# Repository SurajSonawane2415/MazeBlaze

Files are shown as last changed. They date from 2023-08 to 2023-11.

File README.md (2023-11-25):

# MazeBlaze
Develop a Line following and Maze Solving bot based on PID controller that can find the shortest path in a given maze.

## Table of Contents

- [Project](#project)
   - [Table of Contents](#table-of-contents)
   - [About The Project](#about-the-project)
   - [PCB MODEL](#pcb-model)
   - [Demo](#demo)
   - [File Structure](#file-structure)
   - [Getting started](#getting-started)
   - [Future Work](#future-work)
   - [Contributors](#contributors)
   - [Resources](#resources)
   - [Acknowledgements](#acknowledgements)
   - [License](#license)

## About The Project
In this project, we will create a Line-following, Maze-solving bot that can find the shortest path in the given maze.

## Domains Explored
Artificial Intelligence, Embedded C, Control Systems, Graph Algorithms, Electronics and PCB Design

## Project Workflow
- Learning firmware development by completing [Firmware task](https://github.com/SurajSonawane2415/MazeBlaze/tree/main/task/suraj/firmware). And we also understand the firmware used in [SRA Wall-E](https://github.com/SRA-VJTI/Wall-E) and [MazeBlaze-v2](https://github.com/PritK99/MazeBlaze).
- Learning PCB design by completing the line sensor array [pcb_design](https://github.com/SurajSonawane2415/MazeBlaze/tree/main/task/suraj/pcb%20design) task.
- For bot design improvement we created a detailed sheet to make the bot design better. In which we added the advantages and disadvantages of many designs we've reviewed and chosen the best design for the MazeBlaze-v3 bot.
- PCB Design for MazeBlaze-v3 by considering all points to make the bot design better.
- Implementing left follow rule.
- Implementing path planning.
- Implementing dijkstra's algorithm.
- Implementing flood-fill algorithm.
## PCB MODEL

## Demo
### LFR algorithm(Left follow rule):

https://github.com/SurajSonawane2415/MazeBlaze/assets/129578177/a419bddd-6653-45e9-b566-6e79a6069aff

### Dijkstra's algorithm:

https://github.com/SurajSonawane2415/MazeBlaze/assets/129578177/57cf2437-57e8-468f-b269-db0ec31de83d

## File Structure

```
👨‍💻MazeBlaze-v3.1
├ 📂 Firmware
| └ 📂1_left_follow_rule //Contains code for left-follow-rule and path planning
| | ├ 📂main
| | |   ├ 📄1_left_follow_rule.c
| | |   └ 📄CMakeList.txt
| | ├ 📄CMakeList.txt
| ├ 📂2_Dijkstra //Contains code for dijkstra`s algorithm   
| └ 📂Components //Contains all the header and source files used in the project
|   ├ 📂include
|   ├ 📂src
|   ├ 📂esp-wifi-logger
|   ├ 📄CMakeList.txt
├ 📂 assets
├ 📂 documentation //Contains documentation of the project.
├ 📂 pcb_design //Contains pcb_design files of MazeBlaze-v3 board
├ 📂 task
  ├ 📂 Atharv
  | ├ 📂 firmware 
  | |  └📂 1_led_blink.c
  | |    ├ 📂main
  | |    |   ├ 📄1_led_blink.c
  | |    |  └ 📄CMakeList.txt
  | |    ├ 📄CMakeList.txt
  | ├ 📂 pcb_design
  ├ 📂 Suraj
    ├ 📂 firmware //Conatins led blink task files and documentation of the task
    |  └📂 1_led_blink.c 
    |    ├ 📂main
    |    |   ├ 📄1_led_blink.c
    |    |   └ 📄CMakeList.txt
    |    ├ 📄CMakeList.txt
    |    ├ 📄README.md
    ├ 📂 pcb_design //Conatins lsa PCB design task files and documentation of the task
```
## Getting started
### Prerequisites
To download and use this code, the minimum requirements are:
- ESP_IDF
- Windows 7 or later (64-bit), Ubuntu 20.04 or later
- Microsoft VS Code or any other IDE

### Installation
Clone the project by typing the following command in your Terminal/CommandPrompt:
      
     `git clone https://github.com/SurajSonawane2415/MazeBlaze`

Navigate to the MazeBlaze folder:
`cd MazeBlaze`

### Usage

Once the requirements are satisfied, you can easily download the project and use it on your machine. After following the above steps, use the following commands to:

To activate the IDF:
`get_idf`

To build the code:
`idf.py build`

To flash the code:
`idf.py -p (PORT) flash monitor`

## Future Work
- [ ] Implementing better algorithms like DFS/BFS.
- [ ] Achieve higher speeds by increasing the efficiency of the bot.

## Contributors
- [Suraj Sonawane](https://github.com/SurajSonawane2415)
- [Atharva Nerkar](https://github.com/ARN1954)

## Resources
- [MazeBlaze-v2](https://github.com/PritK99/MazeBlaze) GitHub repository of MazeBlaze-v2 
- [MazeBlaze-v1](https://github.com/ChinmayLonkar/MAZEBLAZE) GitHub repository of MazeBlaze-v1
- [Dikstra's](https://www-geeksforgeeks-org.cdn.ampproject.org/v/s/www.geeksforgeeks.org/printing-paths-dijkstras-shortest-path-algorithm/amp/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) Implementation of dijkstr's algorithm in c.
- [Floodfill](https://github.com/Isuru-Dissanayake/piccola) Implementation of the Floodfill algorithm (simulation).

## Acknowledgements 
- [SRA VJTI](https://sravjti.in/) Eklavya 2023
- Special thanks to our mentors [Raj Gupta](https://github.com/RajGupta17), [Prit Kanadiya](https://github.com/PritK99), and all the seniors at SRA, VJTI for their constant support and guidance throughout the project.

## License
[MIT License](https://opensource.org/license/mit/)

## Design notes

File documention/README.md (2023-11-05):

# MazeBlaze-v3.1

# TABLE OF CONTENTS
- [Left Follow Rule (LFR)](#left-follow-rule-lfr)
  - [Theory of LFR](#theory-of-lfr)
  - [Implementation of LFR](#implementation-of-lfr)
  - [Example of LFR](#example-of-lfr)
  - [Description Of Functions Used in LFR](#description-of-functions-used-in-lfr)
  - [Error Descriptions and Solution](#error-descriptions-and-solution)
  - [Problems with Left Follow Rule (LFR) algorithm](#Problems-with-Left-follow-rule-LFR-algorithm)
- [Dijkstra's algorithm](#dijkstras-algorithm)
  - [Theory of Dijkstra's](#theory-of-dijkstras)
  - [Example of Dijkstra's](#example-of-dijkstras)
  - [Implementation of Dijkstra's](#implementation-of-dijkstras)
  - [Description Of Functions Used in Dijkstra's](#description-of-functions-used-in-dijkstras)
- [Printed Circuit Board Design](#printed-circuit-board-design)
  - [Board Images](#board-images)
  - [Routing](#routing)
  - [Major components used in the PCB include](#major-components-used-in-the-pcb-include)
  - [Major Changes for Mazeblaze V3 Board](#major-changes-for-mazeblaze-v3-board)

# Left Follow Rule (LFR)
## Theory of LFR
The Left-Hand Rule (LFR), also known as the "left-follow-algorithm," is a maze-solving technique used to navigate through 2D mazes. To use LFR, you start at the entrance of a maze with your left hand touching the wall to your left. As you navigate through the maze, you follow a set of rules:

1. **Always turn left:** Whenever you reach an intersection or have a choice of paths, you make a left turn if it's possible, keeping your left hand on the wall.

2. **Go straight if a left turn is blocked:** If you come to an intersection where turning left is not an option because it leads to a wall, you continue moving straight while still touching the left wall.

3. **Take a right turn as a last resort:** If you encounter an intersection where you cannot turn left or go straight (usually because of a wall or obstacle), you take a right turn.

4. **Reverse when there are no other options:** If you find yourself in a situation where you can't turn left, go straight, or turn right, it means you've likely reached a dead end. In this case, you need to turn around and backtrack.

## Implementation of LFR
For the implementation of the left-follow rule, we need to record every turn taken by the bot by assigning numeric values to different directions. Then we need to recognize the redundant paths from the given turns.
The directions are indexed as follows:
- North: 1
- East: 2
- South: 3
- West: 4

It is important to note that the algorithm assumes that the bot initially faces the North direction. Subsequently, the other directions are determined based on the North direction. These directions are fixed concerning the world frame, and the bot continually updates its direction as it takes turns. We record the direction index into the `store_path` array, as follows:
1. **Condition for Right Turn**

   When the bot takes a right turn, it increments the `direction` by 1. This is achieved through the code:

   ```c
   direction = (direction + 1) % 4;
   if (direction == 0) direction = 4;
   ```

   This code ensures that the `direction` cycles between 1 and 4, representing North, East, South, and West, respectively.

2. **Condition for Left Turn**

   When the bot takes a left turn, it decrements the `direction` by 1. This is done using:

   ```c
   direction = (direction - 1) % 4;
   if (direction == 0) direction = 4;
   ```

   This code ensures that the `direction` cycles between 1 and 4, representing North, East, South, and West, respectively.

3. **Condition for U-Turn**

   When the bot performs a U-turn, the `direction` is decremented by 2:

   ```c
   direction = (direction - 2) % 4;
   if (direction == 0) direction = 4;
   if (direction == -1) direction = 3;
   ```

   This operation effectively represents a 180-degree turn.

4. **Condition for Moving Straight**

   When the bot continues to move straight, the `direction` remains unchanged:

   ```c
   direction = direction;
   ```

   In this case, the `direction` remains the same, signifying that the bot maintains its current orientation.

When the bot moves and follows these rules, it records its current direction in the store_path array. This helps us keep track of where the bot has been. The bot always knows which direction it's facing, even if it takes many turns.

**Code to store these directions in dry_run array:**
```c
switch (direction) 
        {
            case 1:
                printf("\t North\n");
                store_path[array_index] = 1;
                break;
            case 2:
                printf("\t East\n");
                store_path[array_index] = 2;
                break;
            case 3:
                printf("\t South\n");
                store_path[array_index] = 3;
                break;
            case 4:
                printf("\t West\n");
                store_path[array_index] = 4;
                break;
        }
//store_path[0] = 1 (The direction which the bot faces initially, is always North)
```
## Example 


Thus, for our maze, Assuming the starting position as North i.e. 1, The array store_path[ ] will store the following,

```store_path[ ] = {1, 4, 1, 2, 1, 4, 2, 1, 4, 1, 4, 2, 1, 2, 1, 4, 3, 1, 4, 3, 1, 4, 3, 2, 3, 2, 4, 3, 2, 3, 3, 4, 4, 1, 4, 2, 1, 4, 2, 1, 4, 2, 1, 4, 2, 1, 4, 2, 1}```

Here, the redundant paths are highlighted in bold

store_path[ ] = {1, 4, 1, 2, 1, **4, 2,** 1, 4, 1, **4, 2,** 1, 2, 1, 4, **3, 1,** 4, **3, 1,** 4, 3, 2, 3, **2, 4,** 3, 2, 3, 3, 4, 4, 1, **4, 2,** 1, **4, 2,** 1, **4, 2,** 1, **4, 2,** 1, **4, 2,** 1}

Thus, when we call simply_path(), it removes all these redundancies and stores the shortest path in an array called final_run[ ].

`final_run[ ] = {1,4,1,2,1,1,4,1,1,2,1,4,4,4,3,2,3,3,2,3,3,4,4,1,1,1,1,1,1}`

Thus, we make use of the simplify_path() function in our code to remove all the redundancies from store_path[] and store the shortest path in another array called final_run[].

## Description Of Functions Used

1. 
```c
void LFR()
```
   - **Description:** This function helps the robot explore a maze by following the Left Follow Rule. It detects nodes by using an LSA sensor(Line Sensor Array) and takes turns according to the type of node.

2. 
```c
void Leftturn()
```
   - **Description:** This function tells the bot to turn left by following specific rules for accurate navigation.

3. 
```c
void Rightturn()
```
   - **Description:** This function function tells the bot to turn right by following specific rules for accurate navigation.

4. 
```c
void Uturn()
```
   - **Description:** This function tells the bot to make a U-turn, which means turning around completely to go in the opposite direction, following specific navigation rules.

5. 
```c
void simplify_path()
```
   - **Description:** Removes all the redundancies from store_path[] and stores the shortest path in another array called final_run[].

6. 
```c
void final_maze_solving()
```
   - The `final_maze_solving()` function manages the actual maze-solving process. It guides the robot to follow the simplified path stored in the `final_run` array, ensuring efficient navigation and the avoidance of unnecessary movements while reaching the destination.

## Error Descriptions and Solution
**1: Task Watchdog Triggered**

- **Description:** In the above image, the "Task watchdog got triggered" error message appeared when we flashed our code on the ESP. This error occurs due to the watchdog mechanism in the ESP. The watchdog is like a timer that ensures tasks are completed within their expected time. If a task takes too long to execute, it suggests that there might be a problem with task timing.
The error was triggered because a specific task in our code was exceeding its expected execution time, causing the watchdog to trigger.
- **Solution:** To solve this issue, we added a delay of 10 milliseconds (vTaskDelay(10 / portTICK_PERIOD_MS)) after a specific function. As shown in the following snippet of code: 

```c
get_raw_lsa();
calculate_error();
calculate_correction();

left_duty_cycle = bound((GOOD_DUTY_CYCLE - correction), MIN_DUTY_CYCLE, MAX_DUTY_CYCLE);
right_duty_cycle = bound((GOOD_DUTY_CYCLE + correction), MIN_DUTY_CYCLE, MAX_DUTY_CYCLE);

set_motor_speed(MOTOR_A_1, MOTOR_FORWARD, left_duty_cycle); /* goes forward in this case */
set_motor_speed(MOTOR_A_0, MOTOR_BACKWARD, right_duty_cycle);

vTaskDelay(10 / portTICK_PERIOD_MS); //Delay
```
This allowed the task to be completed within its designated time frame, preventing the watchdog from triggering.

**2:  Unable to turn after detecting a node**
- **Description:** When the bot detects the node after that bot doesn't take a turn. This error was caused because the bot's PWM for the turn was 40, which was insufficient to turn, PWM should be greater than 55 for our case. When the PWM value was set to 40, it likely provided a relatively low average power to the motors, which resulted in the bot's motors not being able to generate enough torque or force to turn effectively.

nt-gif
- **Solution:** We solved the error by increasing the PWM (Pulse Width Modulation) value from 40 to 70 in the motor control configuration, as shown in the following snippet of code: 

 ```c
   #define PWM 85

   void Leftturn() 
   {
     set_motor_speed(MOTOR_A_0, MOTOR_FORWARD, PWM);
     set_motor_speed(MOTOR_A_1, MOTOR_BACKWARD, PWM);
     vTaskDelay(10 / portTICK_PERIOD_MS);
   }
 ```
This PWM adjustment provided the necessary power to the motors, enabling them to turn correctly after node detection. 

**3: Bot Keeps Turning, Doesn't Stop**
- **Description:**  When the bot detected a node and started turning, we added a condition to stop turning when the Line Following Sensor Array (LSA) readings turned white. The error occurred because the turning function was placed within a while loop, and causing the LSA sensor readings to not update as expected. Because of this, the condition does not get satisfied to stop turning. Because of this bot constantly starts taking turns, as shown below:

5-Sep-2023

- **Solution:** To solve this, we added a function called get_raw_lsa() to update the LSA sensor readings. as shown in the following snippet of code:  
```c
   Left turn(){
      while(stop)
      {
        get_raw_lsa();//function to update lsa readings
        set_motor_speed(MOTOR_A_0, MOTOR_BACKWARD, PWM);
        set_motor_speed(MOTOR_A_1, MOTOR_BACKWARD, PWM);

        if (lsa_reading[2] == 1000) //1000=White
        {
            set_motor_speed(MOTOR_A_0, MOTOR_STOP, 0);
            set_motor_speed(MOTOR_A_1, MOTOR_STOP, 0);
            vTaskDelay(20 / portTICK_PERIOD_MS);
            stop=0;
            break;
        }
        vTaskDelay(10 / portTICK_PERIOD_MS);
      }  
       }
```
   With this change, the condition was satisfied, allowing the bot to stop turning correctly when LSA readings became white. As shown in the following video: 

6-Sep-2023

**4: Node Misidentification**

- **Description:** The bot mistakenly identified nodes on straight paths. & after detecting a node bot starts taking. As you can see in the video below:

pt-gif

- **Solution:** To solve this, we performed PID tuning and added flags to check for nodes. When the left or right line sensors detect a white surface (e.g., 1000), a "check flag" is set to true (1). This flag rechecks the condition for nodes, and if it is false, no turn will be taken. As shown in the following snippet of code: 
```c
get_raw_lsa();
left_check = 0;
if ((lsa_reading[0] == 1000) && (lsa_reading[1] == 1000) && (lsa_reading[2] == 1000)) //Left sensor=> lsa_reading[0]
{
    // It detects PLUS NODE & Only Left Node
    printf("leftcheck1\n");
    left_check = 1;
}

if (left_check == 1 )
{
    vTaskDelay(40 / portTICK_PERIOD_MS); // delay
    get_raw_lsa();

    if ((lsa_reading[0] == 1000) && (lsa_reading[1] == 1000) && (lsa_reading[2] == 1000)) // check detected node is node or not.
    {
        left_turn = 1;
    }
    else
    {
        left_check = 0;
    }
}
```
After making all these changes, the bot does not detect nodes on a straight path, even if the bot deviates from a straight line. As you can see in the video below:

7-SEP-2023

**5: Issue with the Final Run**

- **Description:** The problem occurred during the final run., as the bot followed the directions from the `final_run` array after detecting a node. When the bot detects a node the bot should move straight(forward). However, here's where the problem came up: the bot moved forward for only 10 milliseconds. During this short time, it was still on the same node, and as a result, it detected a second node at that same node. The robot then followed the new direction from the `final_run` array. However, the bot can follow only one direction per node to complete the final run successfully. So, because of this bot is not able to complete the final run, and the final run gets destroyed. You can see this issue in the following video:

  WhatsApp Video 2023-10-28 at 03 53 01_90976d8f (1)

- **Solution:** To fix this problem, we made a change in the code. We set a condition that makes the bot keep moving straight until the entire node is ended (either the left or right sensor sees a white surface), which marks the end of a node. With this adjustment, the bot now moves straight through the entire node without detecting multiple nodes. This allowed it to complete the final run without any issues. As shown in the following snippet of code:
```c
void final_straight()
{
    get_raw_lsa();
    while (lsa_reading[0] == 1000 || lsa_reading[4] == 1000) //Left sensor==>0 Right sensor ==>4 WHITE=1000
    {
        get_raw_lsa();
        calculate_error();
        calculate_correction();
    
        left_duty_cycle = bound((GOOD_DUTY_CYCLE - correction), MIN_DUTY_CYCLE, MAX_DUTY_CYCLE);
        right_duty_cycle = bound((GOOD_DUTY_CYCLE + correction), MIN_DUTY_CYCLE, MAX_DUTY_CYCLE);
    
        set_motor_speed(MOTOR_A_1, MOTOR_FORWARD, left_duty_cycle); /*goes forward in this case*/
        set_motor_speed(MOTOR_A_0, MOTOR_BACKWARD, right_duty_cycle);
    
        vTaskDelay(10 / portTICK_PERIOD_MS);
    } 
}
```
You can see this change in action in the video below:

WhatsApp Video 2023-10-28 at 04 04 37_c621a96f (1)

## Problems with the Left Follow Rule (LFR) algorithm
The Left-Follow algorithm helps in reducing the redundancies from the path. However, the problem with the Left-Follow rule is that the entire maze does not get mapped, and thus the path obtained in final_run[ ] is not the most optimum path.

However, The problem with the Left-Follow rule is that the entire maze does not get mapped, and thus the path obtained in final_run[ ] is not the most optimum path. That's why, after this algorithm, we implemented Dijkstra's algorithm, to obtain the shortest path.

# Dijkstra's algorithm
## Theory of Dijkstra's

Dijkstra's algorithm is an algorithm for finding the shortest paths between nodes in a weighted graph. The algorithm maintains a set of visited vertices and a set of unvisited vertices. It starts at the source vertex and iteratively selects the unvisited vertex with the smallest tentative distance from the source. It then visits the neighbors of this vertex and updates their tentative distances if a shorter path is found. This process continues until the destination vertex is reached, or all reachable vertices have been visited.

## Example of Dijkstra's

Suppose we have to find the shortest distance from node 0 to node 6. We would follow these steps.

**Step 1:** Start from Node 0 and mark Node as visited as you can check in the below image visited Node is marked red.

Screenshot from 2023-10-31 23-51-32

**Step 2:** Check for adjacent Nodes, Now we have two choices (Either choose Node1 with distance 2 or choose Node 2 with distance 6 ) and choose Node with minimum distance. In this step Node 1 is the Minimum distance adjacent to Node, so mark it as visited and add up the distance.
Distance: Node 0 -> Node 1 = 2

Screenshot from 2023-10-31 23-51-51

**Step 3:** Then Move Forward and check for the adjacent Node which is Node 3, so mark it as visited and add up the distance, Now the distance will be:
Distance: Node 0 -> Node 1 -> Node 3 = 2 + 5 = 7

Screenshot from 2023-10-31 23-52-10

**Step 4:** Again we have two choices for adjacent Nodes (Either we can choose Node 4 with distance 10 or either we can choose Node 5 with distance 15) so choose Node with minimum distance. In this step Node 4 is the Minimum distance adjacent to Node, so mark it as visited and add up the distance.
Distance: Node 0 -> Node 1 -> Node 3 -> Node 4 = 2 + 5 + 10 = 17

Screenshot from 2023-10-31 23-52-29

**Step 5:** Again, Move Forward and check for the adjacent Node which is Node 6, so mark it as visited and add up the distance, Now the distance will be:
Distance: Node 0 -> Node 1 -> Node 3 -> Node 4 -> Node 6 = 2 + 5 + 10 + 2 = 19

Screenshot from 2023-10-31 23-52-43

## Implementation of Dijkstra's 
**Step I -** First we initialize 3 arrays:-
a)dist[] is an array to store the shortest distance from the source vertex to each vertex in the graph.
b)sptSet[] is a set to keep track of vertices visited in the shortest path(VISITED_NODES).
c)parent[] is an array to store the parent (predecessor) of each vertex in the shortest path.

**Step II -** Then make all elements of dist[]=infinity, sptSet[]=0, parent[]=-1.

**Step III -** 

   ```c
   for (int i = 0; i < V; i++) {
    dist[i] = INT_MAX;
    sptSet[i] = 0;
    parent[i] = -1;
    }

    dist[sourceVertex - 1] = 0;

    for (int count = 0; count < V - 1; count++) {
    int minDist = INT_MAX;
    int minIndex = -1;

    for (int v = 0; v < V; v++) {
    if (sptSet[v] == 0 && dist[v] < minDist) {
    minDist = dist[v];
    minIndex = v;
    }
    }

    sptSet[minIndex] = 1;

    for (int v = 0; v < V; v++) {
    if (!sptSet[v] && costMatrix[minIndex][v] && dist[minIndex] != INT_MAX &&
    dist[minIndex] + costMatrix[minIndex][v] < dist[v]) {
    dist[v] = dist[minIndex] + costMatrix[minIndex][v];
    parent[v] = minIndex;
    }
    }
    }
   ```

With the help of the above code, we update the dist array by storing the values which are the shortest distance of a node from the source.
Here first we make the distance of source to source 0 and then update sptSet and parent array. Then in the last for loop, we check the nearest node to source and update all other arrays. Then again go to the last loop find the nearest node from the last and store the distance between the current 2 nodes + the distance travelled before. Continue this till we reach the last node.

Finally, we get the shortest path stored in the parent array and the shortest distance stored in the distance array at index value = the endpoint.

**Step IV -** 

```c
for (int i = 0; i < size; i++)
    {
    if (finalPathArr[i + 1] - finalPathArr[i] > 1)
    {
    z = (finalPathArr[i + 1] - finalPathArr[i]) - 1;
    for (int j = 0; j < z; j++)
    {
    miss[a] = finalPathArr[i] + c;
    c++;
    a++;
    }
    c=1;
    }
    }
    for(int i=0;i<a; i++){
    k = miss[i];
    dir[k-1]=0;

    }
    for(int i=0;i<x;i++){
    printf(" %d ", dir[i]);
    }

    for(int i =0;i<x;i++){
    if(dir[i]!=0){
    final_run[y] = dir[i];
    y++;
    }
  ```

With the help of the above code, we remove the direction that the bot needs to take to reach the nodes that are not included in the shortest path. And store the directions in final_run that the bot needs to take to follow the shortest path.

## Description Of Functions Used in Dijkstra's

```c
void dijkstra()
```

It is used to find the shortest path from the source to the endpoint and the distance of the shortest path.

```c
void final_traversal()
```

It is used to make the bot travel along the shortest path.

```c
int dir[] = {1,4,1,2,2,1,4,1,4,1,2,1,1,4,1,4,1,4,3,4,3,4,3,2,3,2,3,4,4,2,3,4,3,4,4,1,1,4,4,1,4,1,4,1,4,1,4,1};
```

In it, we have stored the direction that the bot takes to reach a node.

# Printed Circuit Board (PCB) design



## Board images: 
- Front side:



- Back side:



##  Routing:
For routing of the control circuitry we used traces of 0.3mm width, for power connections we used 1.5mm (12v) & 1mm (5v), and for motor control circuitry we used  0.6mm width tracks to ensure fairly high current flow.

- Front copper routing



- Back copper layer:



- Final routing:



## Major components used in the PCB include -

| **Components** | **Description** |
| --- | --- |
| ESP32-WROOM-32E | Microcontroller |
| TB6612FNG | Motor Driver |
| QTR-8RC | Line following reflectance IR sensor array |
| Orange 11.1V 1000mAh 40C 3S | Lithium Polymer Battery | 
|IC LM2576-S-5| Buck Regulator|
|N20-12V-300 Rpm| Motor|

### Power Supply Unit :



Microcontrollers (MCUs) typically operate on 3.3V or 5V logic supply voltage, while the input voltage from the Li-Po battery for our Mazeblaze board's motor driver is 12V.    
So, to have a single input source, a power section which inter converts this 12V to 5V for MCU. This is achieved by using a step-down buck regulator.
Buck Regulator IC LM2576-S-5 is used for stepping down the voltage from 12V to 5V DC.
  
### Motor Driver :



Motors typically run on a 12V power supply, while microcontrollers (MCUs) usually output signals at either 5V or 3.3V. To make these work together, an additional external motor driver circuit is used to control motors according to the MCU input. The current and previous versions of the MazeBlaze board feature the TB6612FNG Motor Driver, a high-performance MOS-based H-Bridge motor driver.

### Protection against Reverse Voltage :
  
In the MazeBlaze Board, we use diodes to shield against reverse voltage in the power line. 12V Motor line, MCU, and buck regulator have been separated with SS34 and SS24 schottky diodes respectively.

### QTR-8RC line following reflectance IR sensor array :
  


The QTR-8RC line following reflectance IR sensor array is used to detect the white/black lined surface and it sends this data to the microcontroller ESP-32. Analyzing and processing the data received by the microcontroller ESP-32, the purpose of line following and node detection is achieved. We use this sensor because it provides precise and reliable line detection, enhancing accuracy and efficiency in tasks like line following and maze navigation. Its infrared sensor ensures stable performance across various surface conditions.

### Orange 11.1V 1000mAh 40C 3S Lithium Polymer Battery :



In the mazeblaze board, we use this battery as a power source for motors & microcontrollers. This battery is operating at 11.1 volts with a 1000mAh capacity, it provides a reliable and sustained power supply. Its high discharge rate of 40C ensures the ability to meet quick and intense power demands, making it an excellent choice for fast maze-solving tasks.

## Major Changes for Mazeblaze V3 Board
| Features | MazeBlaze-V1 | MazeBlaze-V3 |
| --- | --- | --- |
| Sensor | TCRT5000 IR SENSOR | QTR-8RC line following reflectance IR sensor array |
| Sensor Placement |on the main PCB and near the wheels|Placed apart from the main PCB, the sensor can be adjustable and not close to the wheels.|
| Battery | 3.7v Li-Po battery |11.1V 1000mAh 40C 3S Li-Po Battery |
| Power Supply Unit| MT3608 Step UP Boost Converter is used for stepping up the voltage from 3.7V DC to 6V.|Buck Regulator IC LM2576-S-5 is used for stepping down the voltage from 12V to 5V DC|

### MT3608 Step UP Boost Converter to LM2576/96 Buck Convertor
In the MazeBlaze-V1 board, we used a 3.7V battery supply for the motors, that's why we require an MT3608 boost converter to step up the voltage from 3.7V to 6V for 6V N20 motors. However, in the MazeBlaze-V3 board, we utilize an 11.1V power source for 12V N20 motors, eliminating the need for a boost converter. For the MCU (ESP), we require a 5V supply, for which we use a buck converter LM2576/96 due to their superior efficiency, higher output current, and increased reliability. The LM2576 has an efficiency of up to 92%.

### TCRT5000 IR SENSOR to QTR-8RC line following reflectance IR sensor array
In the MazeBlaze-V1 board for line following and node detection, we use TCRT5000 IR sensors but these sensors are not more efficient in maze solving. So, now in MazeBlaze-v3, we using a QTR-8RC IR sensor. QTR-8RC is chosen because of its enhanced resolution, wider range, and reduced interference, offering improved line-following precision and adaptability, vital for our maze-solving bot project.

### 3.7v Li-Po battery to 11.1V 1000mAh 40C 3S Li-Po Battery
In MazeBlaze-v1, we used a 3.7V battery, but the motors needed more voltage, so we used an MT3608 Step-Up Boost Converter to raise it to 6V. In MazeBlaze-v3, we switched to 12V N20 motors, so we used an 11.1V 1000mAh 40C 3S Li-Po Battery, it also eliminates the need for a boost converter and is also lightweight and not bulky.

### Sensor Placement on the main PCB to Placed apart from the main PCB
In MazeBlaze-v1, the line sensor array was placed very close to the wheels, which didn't allow the bot enough time to turn after detecting a node. This limitation prevented the bot from running at high speeds. To address this issue in MazeBlaze-V3, we positioned the sensors further apart from the main PCB, allowing us to adjust their placement as needed.

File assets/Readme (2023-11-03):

This folder contains all the images of PCB design and  videos of algorithm implementation.

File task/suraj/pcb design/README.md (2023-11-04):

# PCB Design Task:
In this task I designed a PCB for line sensor array(LSA) used in [SRA board](https://github.com/SRA-VJTI/sra-board-hardware-design). 
## Board images:
- Front side:
  
- Back side:
  

## Routing:
For routing of the control circuitry and power connections we used traces of 0.3mm width.
- Back copper routing


## Overview:
The Line Sensor Array (LSA) uses TCRT 5000 sensors to detect white and black lines on the surface. It then sends this data to the ESP-32 microcontroller. By analyzing and processing the data, the microcontroller ESP-32 accomplishes the task of line following.

## TCRT 5000
The TCRT 5000 is an optical sensor module commonly used for detecting the presence of objects or lines. It consists of an infrared (IR) emitter and a phototransistor. The emitter emits infrared light, which bounces off objects or surfaces and is detected by the phototransistor. The amount of reflected light is used to determine the proximity of an object or the presence of a surface, typically a white or black line. TCRT 5000 sensors are often employed in applications like line-following bot.



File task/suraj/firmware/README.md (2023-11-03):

# Firmware task
In this task, we write an ESP-IDF code to blink an LED without using the "sra_board.h" header file, which is used in the ["Wall-E 1_led_blink"](https://github.com/SRA-VJTI/Wall-E/tree/master/1_led_blink) code.

## Terms used
### GPIO Configuration
GPIO (General Purpose Input/Output) pins on microcontrollers are often configured to either input or output mode. When a pin is configured as an output, it can be used to control external devices like LEDs, motors, or sensors. Configuration typically involves specifying the pin, its mode, and any additional settings like pull-up or pull-down resistors.
**Code Snippet for GPIO Configuration**:
```c
// Configuration for GPIO pin 12 as an output with a pull-down resistor
gpio_config_t io_conf;
io_conf.pin_bit_mask = (1ULL << GPIO_NUM_12);  // Pin bitmask
io_conf.mode = GPIO_MODE_OUTPUT;  // Set the pin as an output
io_conf.pull_up_en = 0;  // Disable pull-up resistor
io_conf.pull_down_en = 1;  // Enable pull-down resistor
io_conf.intr_type = GPIO_INTR_DISABLE;  // Disable interrupt handling

esp_err_t err = gpio_config(&io_conf);
if (err != ESP_OK) {
   // Handle configuration error
}
```
In this snippet, `gpio_config_t` is a structure used to configure the GPIO pins. The `io_conf` structure specifies the pin bitmask, mode (output in this case), pull-up and pull-down settings, and interrupt handling. If the configuration fails, an error can be handled accordingly.

### Bit Masking
Bit masking is a technique used to manipulate and extract specific bits within a binary number. It's often used in microcontroller programming to set or clear individual bits in a register, which can control various hardware components.
For example, bit masking is use to set a specific bit to 1 while keeping all other bits unchanged. In C, the | (OR) operator for setting bits and the & (AND) operator to clear bits.
**Code Snippet for Bit Masking**:
```c
// Setting bit 2 to 1, assuming a 3-bit binary number
uint8_t data = 0b00000100;  // Binary representation
uint8_t bitmask = 0b00000100;  // Mask with a 1 in the desired bit
data |= bitmask;  // Setting the bit to 1

// Clearing bit 3 to 0
uint8_t data2 = 0b00001000;
uint8_t bitmask2 = 0b11110111;  // Mask with 0 in the desired bit
data2 &= bitmask2;  // Clearing the bit to 0
```
These snippets demonstrate bit masking for manipulating individual bits in binary data and configuring a GPIO pin for output with specific settings.

## Output:
task (1)

## Refernces
- [SRA Embedded system study group](https://sravjti.in/embedded-systems-study-group/week5/week5.html) refernce for bit masking.
- [ESP-32 GPIO configuration guide](https://docs.espressif.com/projects/esp-idf/en/latest/esp32/api-reference/peripherals/gpio.html) GPIO configuration refernce.

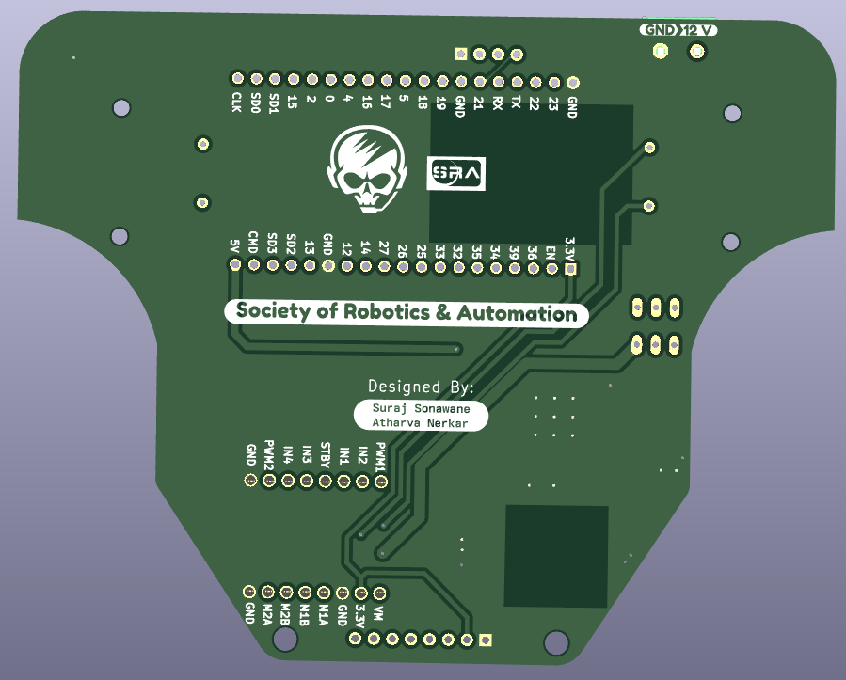
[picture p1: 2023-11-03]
assets/back.png

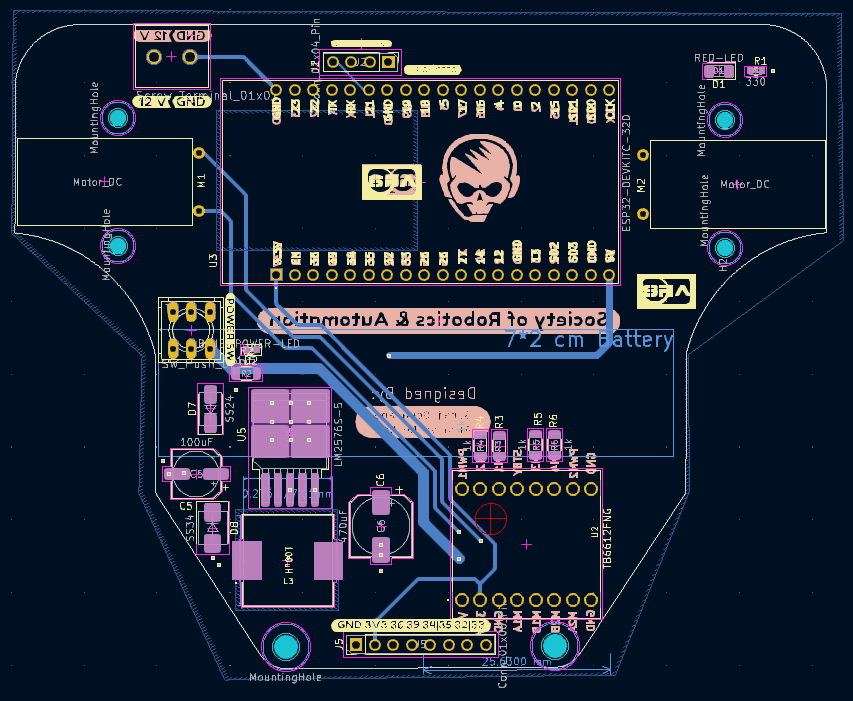
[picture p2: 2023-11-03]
assets/Bcu.png

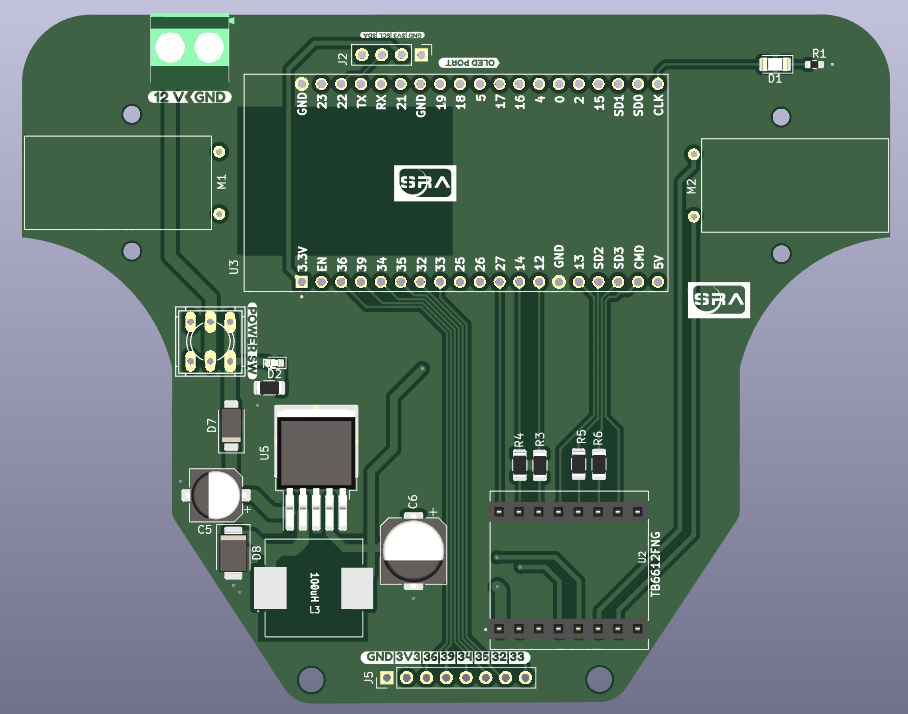
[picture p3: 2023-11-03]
assets/front.png

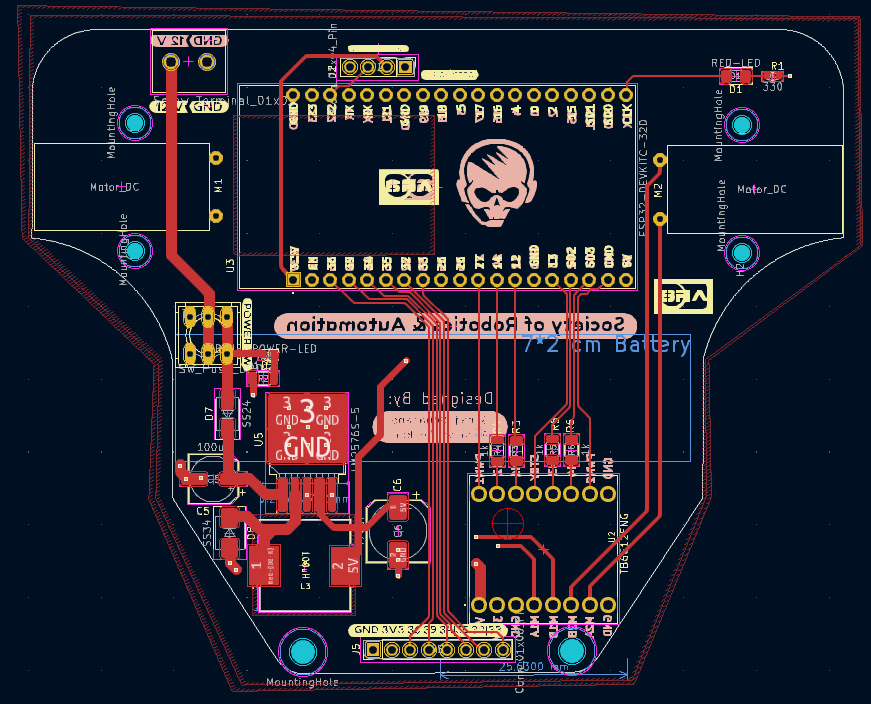
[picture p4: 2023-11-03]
assets/Fcu.png

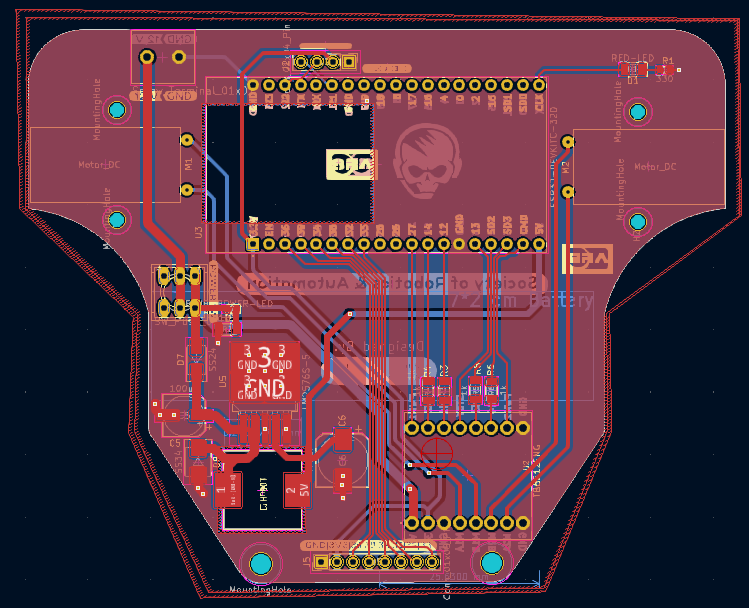
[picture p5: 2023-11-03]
assets/routing.png

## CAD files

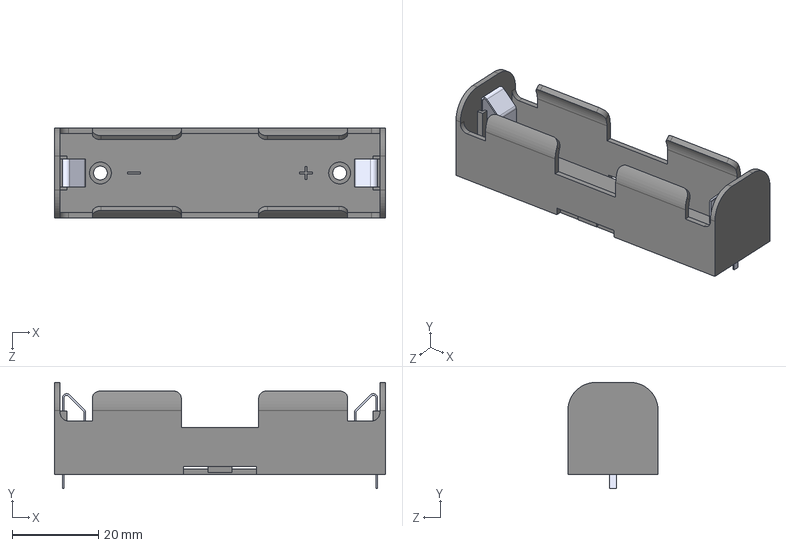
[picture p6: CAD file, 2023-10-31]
pcb_design/3d_models/BK-18650-PC2.step
77.0 x 24.7 x 21.0 mm

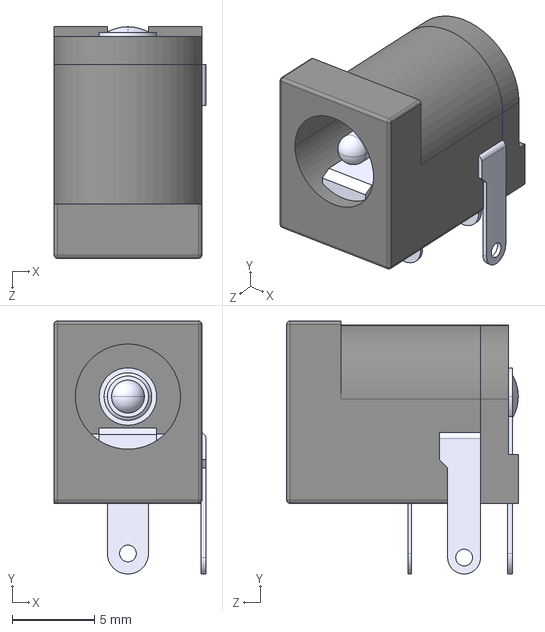
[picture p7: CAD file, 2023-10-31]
pcb_design/3d_models/CON-SOCJ-2155--3DModel-STEP-56544.STEP
9.25 x 15.4 x 14.1 mm

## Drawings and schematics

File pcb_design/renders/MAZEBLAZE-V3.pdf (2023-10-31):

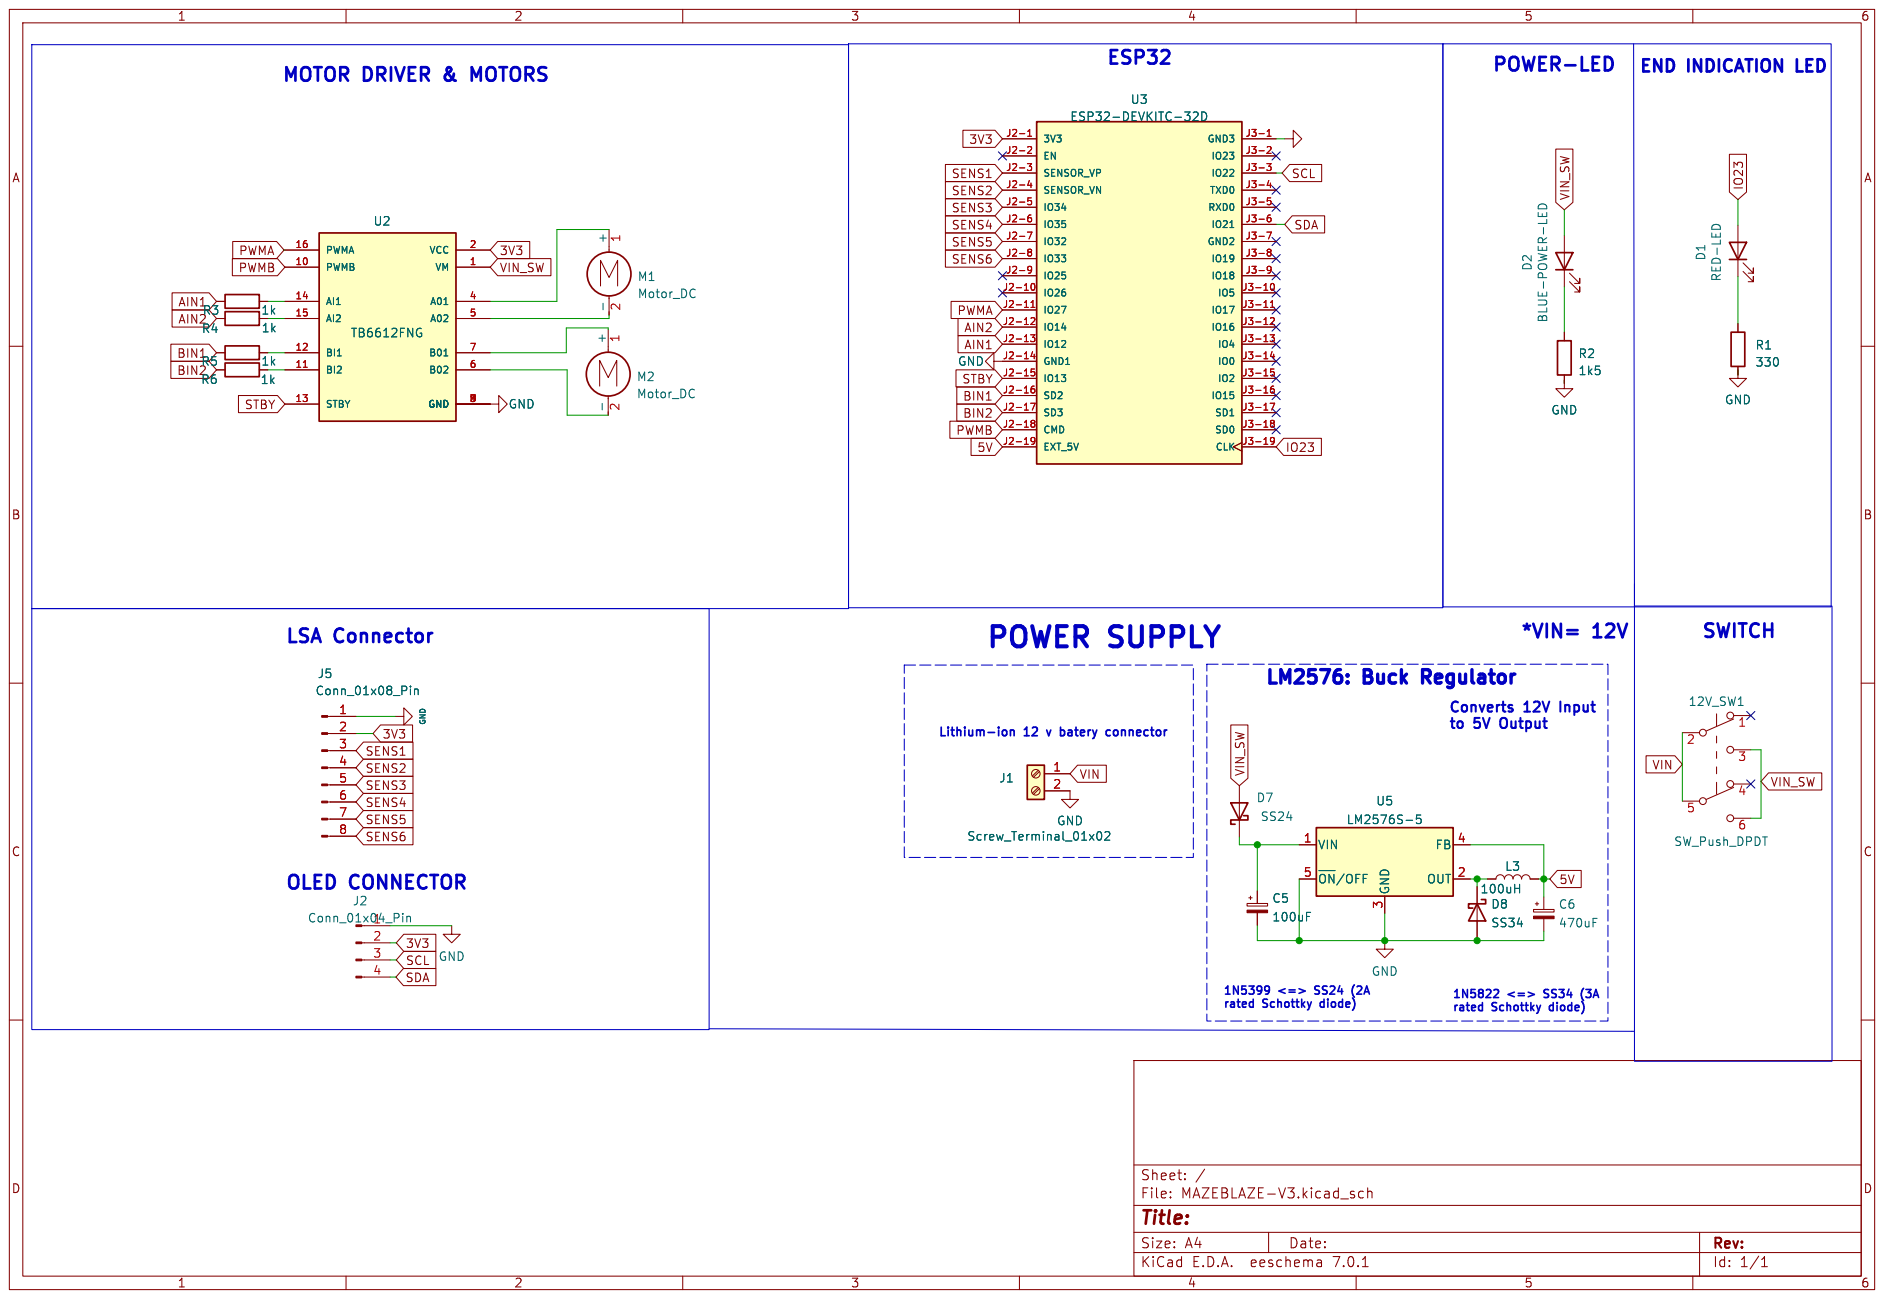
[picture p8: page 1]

rated Schottky diode) MOTOR DRIVER & MOTORS

330 GND D2 BLUE-POWER-LED GND

LM2576: Buck Regulator Converts 12V Input

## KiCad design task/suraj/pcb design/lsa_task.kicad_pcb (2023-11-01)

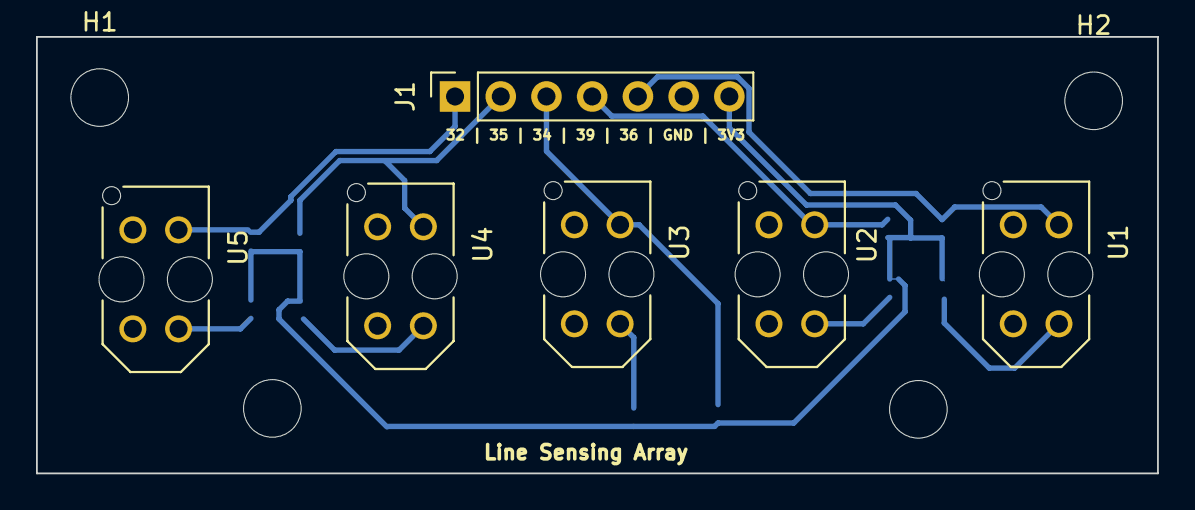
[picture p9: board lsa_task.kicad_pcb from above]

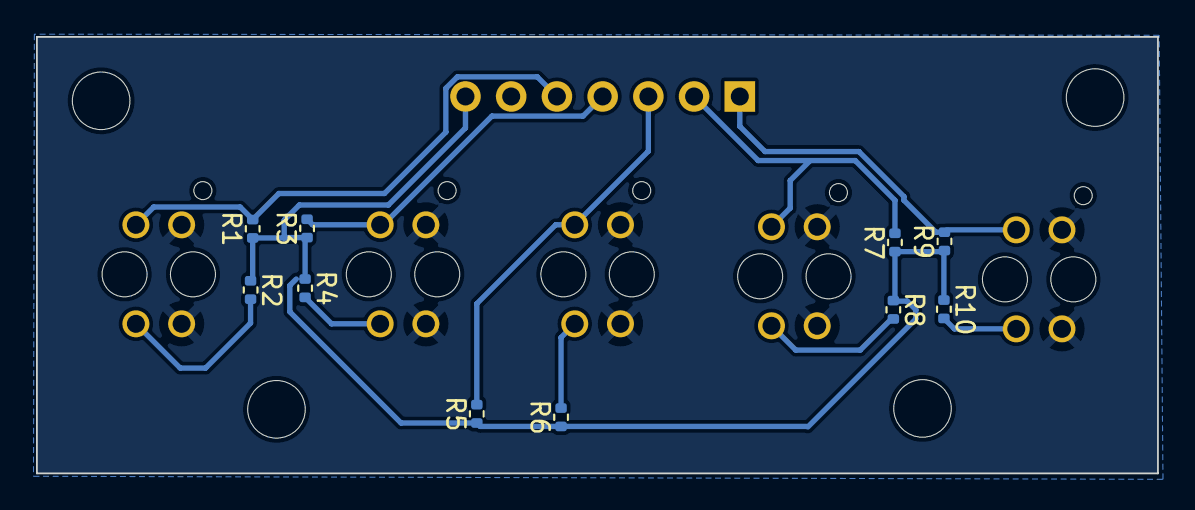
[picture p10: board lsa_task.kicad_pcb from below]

Board: 2 copper layers, 62.3 x 24.2 mm, 20 parts (10 on the bottom side), 12 nets.

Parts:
H1, H2, H3, H4: MountingHole_Pad; MountingHole_3.2mm_M3
J1: Conn_01x07_Pin; PinSocket_1x07_P2.54mm_Vertical
R1, R3, R5, R7, R9: 4k7; R_0402_1005Metric
R2, R4, R6, R8, R10: 1K; R_0402_1005Metric
U1, U2, U3, U4, U5: TCRT5000; OPTO_TCRT5000

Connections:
3V3: J1.7, R1.1, R2.1, R3.1, R4.1, R5.1, R6.1, R7.1, R8.1, R9.1, R10.1
A0_36: J1.5, R1.2, U1.COLL
A1_39: J1.4, R3.2, U2.COLL
A2_34: J1.3, R5.2, U3.COLL
A3_35: J1.2, R7.2, U4.COLL
A4_32: J1.1, R9.2, U5.COLL
GND: J1.6, U1.CATH, U1.E, U2.CATH, U2.E, U3.CATH, U3.E, U4.CATH, U4.E, U5.CATH, U5.E
unnamed: R2.2, U1.A
unnamed: R4.2, U2.A
unnamed: R6.2, U3.A
unnamed: R8.2, U4.A
unnamed: R10.2, U5.A

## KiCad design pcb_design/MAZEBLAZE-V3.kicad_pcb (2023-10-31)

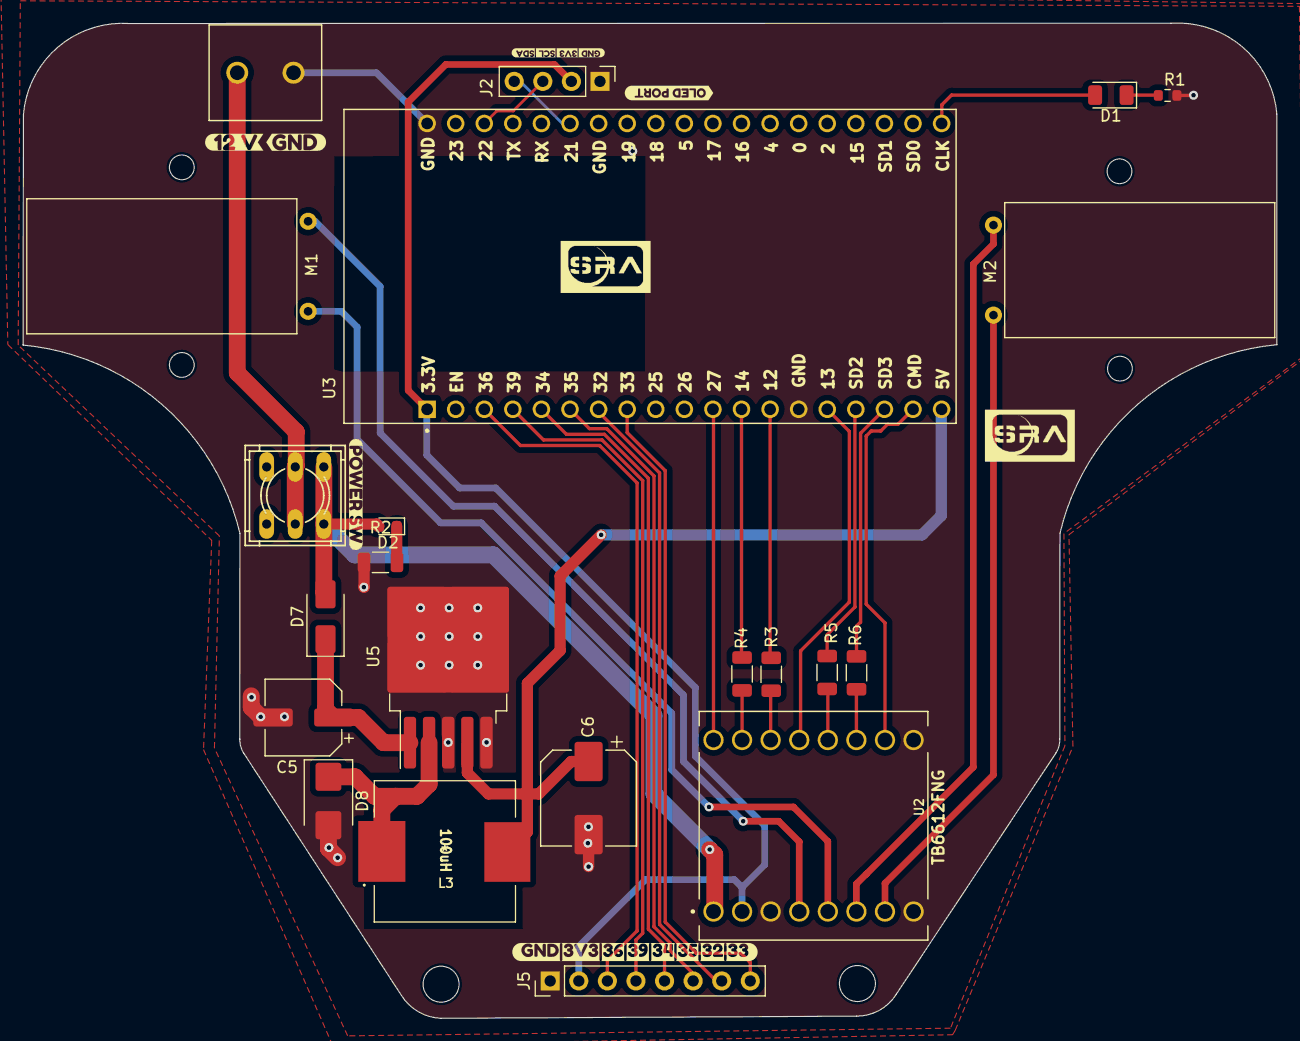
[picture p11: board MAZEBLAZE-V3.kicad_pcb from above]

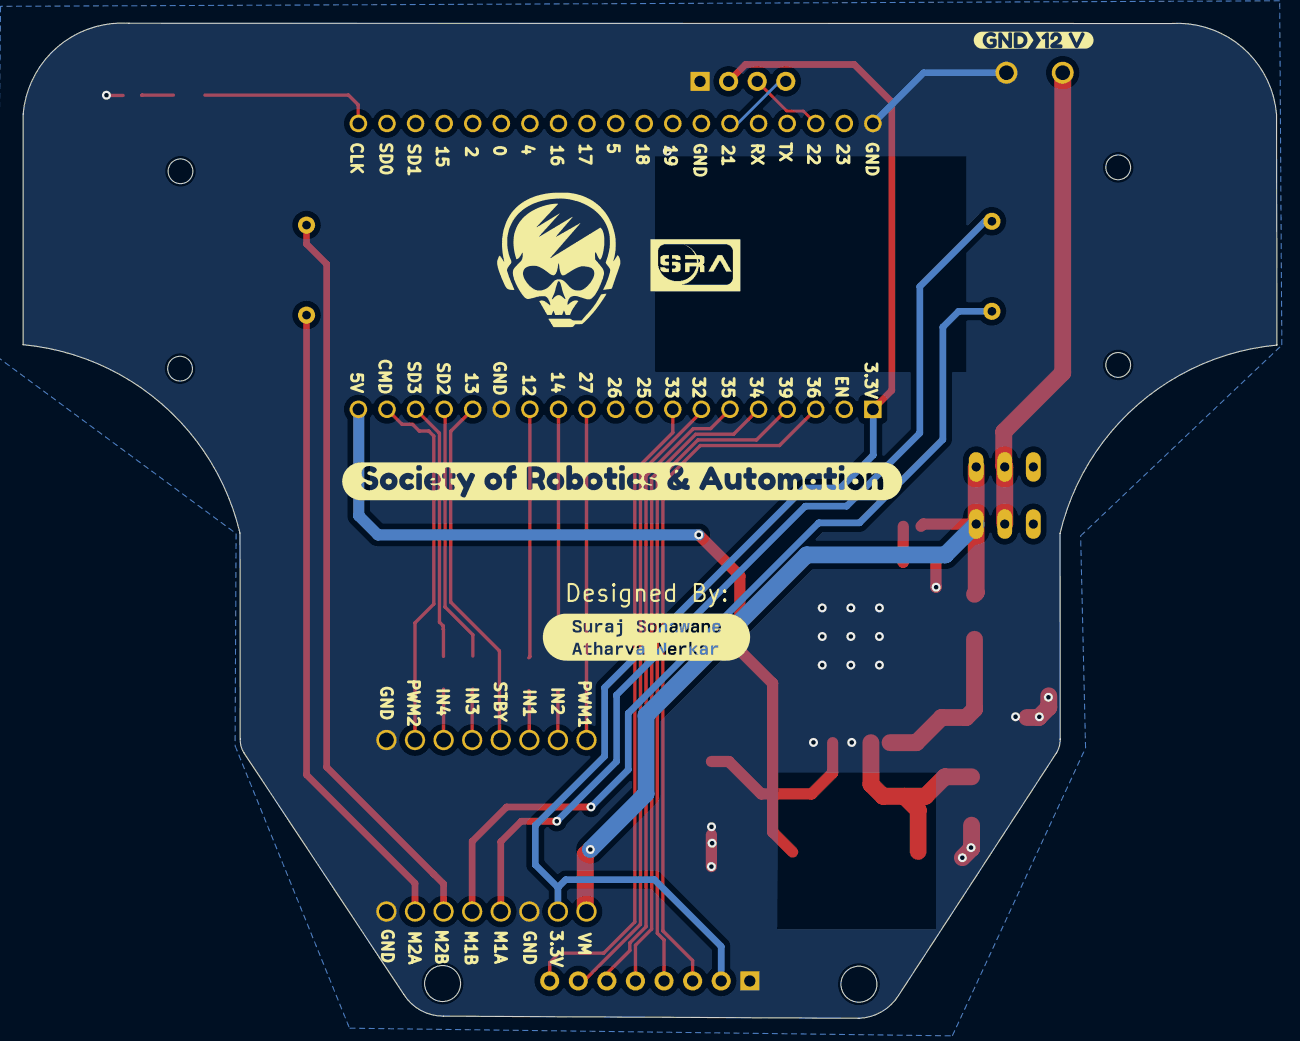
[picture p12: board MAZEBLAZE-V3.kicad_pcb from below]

Board: 2 copper layers, 111.4 x 88.4 mm, 38 parts (4 on the bottom side), 33 nets.

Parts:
12V_SW1: SW_Push_DPDT; dpdt_sw_2x03_tht
C5: 100uF; CP_Elec_6.3x7.7
C6: 470uF; CP_Elec_8x10
D1: RED-LED; LED_1206_3216Metric
D2: BLUE-POWER-LED; LED_0603_1608Metric
D7: SS24; D_SMA
D8: SS34; D_SMB
H1, H2#2, H3, H4: MountingHole; MountingHole_2.2mm_M2
H2, H5: MountingHole; MountingHole_3.2mm_M3
J1: Screw_Terminal_01x02; 12V_1x02_tht
J2: Conn_01x04_Pin; PinHeader_1x04_P2.54mm_Vertical
J5: Conn_01x08_Pin; PinHeader_1x08_P2.54mm_Vertical
L3: 100uH; CDRH127_inductor_smd
M1, M2: Motor_DC; N20_Motor
R1: 330; R_0603_1608Metric
R2: 1k5; R_1206_3216Metric
R3, R4, R5, R6: 1k; R_1206_3216Metric
U2: TB6612FNG; TB6612FNG_2
U3: ESP32-DEVKITC-32D; MODULE_ESP32-DEVKITC-32D
U5: LM2576S-5; TO-263-5_TabPin3
kibuzzard-61F7FB1D: G***; kibuzzard-61F7FB1D
kibuzzard-61F7FBA3: G***; kibuzzard-61F7FBA3
kibuzzard-61F7FBC2: G***; kibuzzard-61F7FBC2
kibuzzard-61F7147A: G***; kibuzzard-61F7147A
kibuzzard-61F71491: G***; kibuzzard-61F71491
kibuzzard-637A1A13: G***; kibuzzard-637A1A13
kibuzzard-653BE6A4: G***; kibuzzard-653BE6A4
kibuzzard-653BE7A2: G***; kibuzzard-653BE7A2
kibuzzard-653BEE79: G***; kibuzzard-653BEE79
kibuzzard-653E5949: G***; kibuzzard-653E5949

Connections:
3V3: J2.2, J5.2, U2.2 (VCC), U3.J2-1 (3V3)
5V: C6.1, L3.2, U3.J2-19 (EXT_5V), U5.4 (FB)
AIN1: R3.1, U3.J2-13 (IO12)
AIN2: R4.1, U3.J2-12 (IO14)
BIN1: R5.1, U3.J2-16 (SD2)
BIN2: R6.1, U3.J2-17 (SD3)
GND: C5.2, C6.2, D8.2 (A), J1.2, J2.1, J5.1, R1.2, R2.2, U2.3 (GND), U2.8 (GND), U2.9 (GND), U3.J2-14 (GND1), U3.J3-1 (GND3), U5.3 (GND), U5.5 (~ON/OFF)
IO23: D1.2 (A), U3.J3-19 (CLK)
unnamed: D1.1 (K), R1.1
unnamed: D2.1 (K), R2.1
unnamed: C5.1, D7.1 (K), U5.1 (VIN)
unnamed: D8.1 (K), L3.1, U5.2 (OUT)
unnamed: M1.1 (+), U2.4 (A01)
unnamed: M1.2 (-), U2.5 (A02)
unnamed: M2.1 (+), U2.7 (B01)
unnamed: M2.2 (-), U2.6 (B02)
unnamed: R3.2, U2.14 (AI1)
unnamed: R4.2, U2.15 (AI2)
unnamed: R5.2, U2.12 (BI1)
unnamed: R6.2, U2.11 (BI2)
PWMA: U2.16 (PWMA), U3.J2-11 (IO27)
PWMB: U2.10 (PWMB), U3.J2-18 (CMD)
SCL: J2.3, U3.J3-3 (IO22)
SDA: J2.4, U3.J3-6 (IO21)
SENS1: J5.3, U3.J2-3 (SENSOR_VP)
SENS2: J5.4, U3.J2-4 (SENSOR_VN)
SENS3: J5.5, U3.J2-5 (IO34)
SENS4: J5.6, U3.J2-6 (IO35)
SENS5: J5.7, U3.J2-7 (IO32)
SENS6: J5.8, U3.J2-8 (IO33)
STBY: U2.13 (STBY), U3.J2-15 (IO13)
VIN: 12V_SW1.2 (B), 12V_SW1.5 (B), J1.1
VIN_SW: 12V_SW1.3 (C), 12V_SW1.6 (C), D2.2 (A), D7.2 (A), U2.1 (VM)

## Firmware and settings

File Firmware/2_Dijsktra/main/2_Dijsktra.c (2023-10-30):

#include <stdio.h>
#include <stdlib.h>
#include "mazeblaze3.h"
#include "tuning_http_server.h"
#include "driver/gpio.h"

float error = 0, prev_error = 0, difference, cumulative_error, correction;
float left_duty_cycle = 0, right_duty_cycle = 0;

float kp = 35, ki = 0.01, kd = 60;

const int weights[5] = {3, 1, 0, -1, -3};

int final_run[50];
int array_index = 1;
int f=1;
TaskHandle_t taskhandle1 = NULL;

#define INFINITY_A 999
#define V 48

/*This method involves tuning kp , ski ,kd physically*/
#define GOOD_DUTY_CYCLE 91
#define MIN_DUTY_CYCLE 61
#define MAX_DUTY_CYCLE 86
int path_length = 0;
int enable_path_matrix=1;
int stop_path_matrix=1;


/*FINAL TURN FLAGS*/
int left_final_check=0;
int right_final_check=0;
int final_left_turn_check=0;
int final_right_turn_check=0;
int take_final_right_turn=0;
int take_final_left_turn=0;
int take_straight=0;
int stop=0;
int x = 0;
int left_check = 0;
int right_check = 0;
int left_turn_check = 0;
int left_turn=0;
int right_turn = 0;
int left_tune = 0;
int only_right = 0;
int uturn_tune = 0;
int right_tune = 0;
int Check_End=0;

#define PWM 85
int rotation1 = 0;
bool rotation2 = false;

int costMatrix[V][V] = {
 {0, 2, 0, 0, 0, 0, 0, 0, 0, 0, 0, 0, 0, 0, 0, 0, 0, 0, 0, 0, 0, 0, 0, 0, 0, 0, 0, 0, 0, 0, 0, 0, 0, 0, 0, 0, 0, 0, 0, 0, 0, 0, 0, 0, 0, 0, 0, 0},
 {0, 0, 2, 0, 0, 0, 0, 0, 0, 0, 0, 0, 0, 0, 0, 0, 0, 0, 0, 0, 0, 0, 0, 0, 0, 0, 0, 0, 0, 0, 0, 0, 0, 0, 0, 0, 0, 0, 0, 0, 0, 0, 0, 0, 0, 0, 0, 0},
 {0, 0, 0, 2, 0, 0, 0, 0, 0, 0, 0, 0, 0, 0, 0, 0, 0, 0, 0, 0, 0, 0, 0, 0, 0, 0, 0, 0, 0, 0, 0, 0, 0, 0, 0, 0, 0, 0, 0, 0, 0, 0, 0, 0, 0, 0, 0, 0},
 {0, 0, 0, 0, 2, 2, 0, 0, 0, 0, 0, 0, 0, 0, 0, 0, 0, 0, 0, 0, 0, 0, 0, 0, 0, 0, 0, 0, 0, 0, 0, 0, 0, 0, 0, 0, 0, 0, 0, 0, 0, 0, 0, 0, 0, 0, 0, 0},
 {0, 0, 0, 0, 0, 0, 0, 0, 0, 0, 0, 0, 0, 0, 0, 0, 0, 0, 0, 0, 0, 0, 0, 0, 0, 0, 0, 0, 0, 0, 0, 0, 0, 0, 0, 0, 0, 0, 0, 0, 0, 0, 0, 0, 0, 0, 0, 0},
 {0, 0, 0, 0, 0, 0, 2, 2, 0, 0, 0, 0, 0, 0, 0, 0, 0, 0, 0, 0, 0, 0, 0, 0, 0, 0, 0, 0, 0, 0, 0, 0, 0, 0, 0, 0, 0, 0, 0, 0, 0, 0, 0, 0, 0, 0, 0, 0},
 {0, 0, 0, 0, 0, 0, 0, 0, 0, 0, 0, 0, 0, 0, 0, 0, 0, 0, 0, 0, 0, 0, 0, 0, 0, 0, 0, 0, 0, 0, 0, 0, 0, 0, 0, 0, 0, 0, 0, 0, 0, 0, 0, 0, 0, 0, 0, 0},
 {0, 0, 0, 0, 0, 0, 0, 0, 2, 2, 2, 0, 0, 0, 0, 0, 0, 0, 0, 0, 0, 0, 0, 0, 0, 0, 0, 0, 0, 0, 0, 0, 0, 0, 0, 0, 0, 0, 0, 0, 0, 0, 0, 0, 0, 0, 0, 0},
 {0, 0, 0, 0, 0, 0, 0, 0, 0, 0, 0, 2, 0, 0, 0, 0, 0, 0, 0, 0, 0, 0, 0, 0, 0, 0, 0, 0, 0, 0, 0, 0, 0, 0, 0, 0, 0, 0, 0, 0, 0, 0, 0, 0, 0, 0, 0, 0},
 {0, 0, 0, 0, 0, 0, 0, 0, 0, 0, 0, 0, 0, 0, 0, 0, 0, 0, 0, 0, 0, 0, 0, 0, 0, 0, 0, 0, 0, 0, 0, 0, 0, 0, 0, 0, 0, 0, 0, 0, 0, 0, 0, 0, 0, 0, 0, 0},
 {0, 0, 0, 0, 0, 0, 0, 0, 0, 0, 0, 0, 2, 0, 0, 0, 0, 0, 0, 0, 0, 0, 0, 0, 0, 0, 0, 0, 0, 0, 0, 0, 0, 0, 0, 0, 0, 0, 0, 0, 0, 0, 0, 0, 0, 0, 0, 0},
 {0, 0, 0, 0, 0, 0, 0, 0, 0, 0, 0, 0, 0, 2, 2, 0, 0, 0, 0, 0, 0, 0, 0, 0, 0, 0, 0, 0, 0, 0, 0, 0, 0, 0, 0, 0, 0, 0, 0, 0, 0, 0, 0, 0, 0, 0, 0, 0},
 {0, 0, 0, 0, 0, 0, 0, 0, 0, 0, 0, 0, 0, 0, 0, 2, 0, 0, 0, 0, 0, 0, 0, 0, 0, 0, 0, 0, 0, 0, 0, 0, 0, 0, 0, 0, 0, 0, 0, 0, 0, 0, 0, 0, 0, 0, 0, 0},
 {0, 0, 0, 0, 0, 0, 0, 0, 0, 0, 0, 0, 0, 0, 0, 0, 0, 0, 0, 0, 0, 0, 0, 0, 0, 0, 0, 0, 0, 0, 0, 0, 0, 0, 0, 0, 0, 0, 0, 0, 0, 0, 0, 0, 0, 0, 0, 0},
 {0, 0, 0, 0, 0, 0, 0, 0, 0, 0, 0, 0, 0, 0, 0, 2, 0, 0, 0, 0, 0, 0, 0, 0, 0, 0, 0, 0, 0, 0, 0, 0, 0, 0, 0, 0, 0, 0, 0, 0, 0, 0, 0, 0, 0, 0, 0, 0},
 {0, 0, 0, 0, 0, 0, 0, 0, 0, 0, 0, 0, 0, 0, 0, 0, 2, 0, 0, 0, 0, 0, 0, 0, 0, 0, 0, 0, 0, 0, 0, 0, 0, 0, 0, 0, 0, 0, 0, 0, 0, 0, 0, 0, 0, 0, 0, 0},
 {0, 0, 0, 0, 0, 0, 0, 0, 0, 0, 0, 0, 0, 0, 0, 0, 0, 3, 0, 0, 0, 0, 0, 0, 0, 0, 0, 0, 0, 0, 0, 0, 0, 0, 0, 0, 0, 0, 0, 0, 0, 0, 0, 0, 0, 0, 0, 0},
 {0, 0, 0, 0, 0, 0, 0, 0, 0, 0, 0, 0, 0, 0, 0, 0, 0, 0, 2, 2, 0, 0, 0, 0, 0, 0, 0, 0, 0, 0, 0, 0, 0, 0, 0, 0, 0, 0, 0, 0, 0, 0, 0, 0, 0, 0, 0, 0},
 {0, 0, 0, 0, 0, 0, 0, 0, 0, 0, 0, 0, 0, 0, 0, 0, 0, 0, 0, 0, 0, 0, 0, 0, 0, 0, 0, 0, 0, 0, 0, 0, 0, 0, 0, 0, 0, 0, 0, 0, 0, 0, 0, 0, 0, 0, 0, 0},
 {0, 0, 0, 0, 0, 0, 0, 0, 0, 0, 0, 0, 0, 0, 0, 0, 0, 0, 0, 0, 2, 2, 0, 0, 0, 0, 0, 0, 0, 0, 0, 0, 0, 0, 0, 0, 0, 0, 0, 0, 0, 0, 0, 0, 0, 0, 0, 0},
 {0, 0, 0, 0, 0, 0, 0, 0, 0, 0, 0, 0, 0, 0, 0, 0, 0, 0, 0, 0, 0, 0, 0, 0, 0, 0, 0, 0, 0, 0, 0, 0, 0, 0, 0, 0, 0, 0, 0, 0, 0, 0, 0, 0, 0, 0, 0, 0},
 {0, 0, 0, 0, 0, 0, 0, 0, 0, 0, 0, 0, 0, 0, 0, 0, 0, 0, 0, 0, 0, 0, 4, 0, 0, 0, 0, 0, 0, 0, 0, 0, 0, 0, 0, 0, 0, 0, 0, 0, 0, 0, 0, 0, 0, 0, 0, 0},
 {0, 0, 0, 0, 0, 0, 0, 0, 0, 0, 0, 0, 0, 0, 0, 0, 0, 0, 0, 0, 0, 0, 0, 2, 0, 0, 0, 0, 0, 0, 0, 0, 0, 0, 0, 0, 0, 0, 0, 0, 0, 0, 0, 0, 0, 0, 0, 0},
 {0, 0, 0, 0, 0, 0, 0, 0, 0, 0, 0, 0, 0, 0, 0, 0, 0, 0, 0, 0, 0, 0, 0, 0, 2, 0, 0, 0, 0, 0, 0, 0, 0, 0, 0, 0, 0, 0, 0, 0, 0, 0, 0, 0, 0, 0, 0, 0},
 {0, 0, 0, 0, 0, 0, 0, 0, 0, 0, 0, 0, 0, 0, 0, 0, 0, 0, 0, 0, 0, 0, 0, 0, 0, 2, 2, 2, 0, 0, 0, 0, 0, 0, 0, 0, 0, 0, 0, 0, 0, 0, 0, 0, 0, 0, 0, 0},
 {0, 0, 0, 0, 0, 0, 0, 0, 0, 0, 0, 0, 0, 0, 0, 0, 0, 0, 0, 0, 0, 0, 0, 0, 0, 0, 0, 0, 0, 0, 0, 0, 0, 0, 0, 0, 0, 0, 0, 0, 0, 0, 0, 0, 0, 0, 0, 0},
 {0, 0, 0, 0, 0, 0, 0, 0, 0, 0, 0, 0, 0, 0, 0, 0, 0, 0, 0, 0, 0, 0, 0, 0, 0, 0, 0, 0, 0, 2, 0, 0, 0, 0, 0, 0, 0, 0, 0, 0, 0, 0, 0, 0, 0, 0, 0, 0},
 {0, 0, 0, 0, 0, 0, 0, 0, 0, 0, 0, 0, 0, 0, 0, 0, 0, 0, 0, 0, 0, 0, 0, 0, 0, 0, 0, 0, 2, 0, 0, 0, 0, 0, 0, 0, 0, 0, 0, 0, 0, 0, 0, 0, 0, 0, 0, 0},
 {0, 0, 0, 0, 0, 0, 0, 0, 0, 0, 0, 0, 0, 0, 0, 0, 0, 0, 0, 0, 0, 0, 0, 0, 0, 0, 2, 0, 0, 0, 0, 0, 0, 0, 0, 0, 0, 0, 0, 0, 0, 0, 0, 0, 0, 0, 0, 0},
 {0, 0, 0, 0, 0, 0, 0, 0, 0, 0, 0, 0, 0, 0, 0, 0, 0, 0, 0, 0, 0, 0, 0, 0, 0, 0, 0, 0, 0, 0, 2, 0, 0, 0, 0, 0, 0, 0, 0, 0, 0, 0, 0, 0, 0, 0, 0, 0},
 {0, 0, 0, 0, 0, 0, 0, 0, 0, 0, 0, 0, 0, 0, 0, 0, 0, 0, 0, 0, 0, 0, 0, 0, 0, 0, 0, 0, 0, 0, 0, 4, 4, 0, 0, 0, 0, 0, 0, 0, 0, 0, 0, 0, 0, 0, 0, 0},
 {0, 0, 0, 0, 0, 0, 0, 0, 0, 0, 0, 0, 0, 0, 0, 0, 0, 0, 0, 0, 0, 0, 0, 0, 0, 0, 0, 0, 0, 0, 0, 0, 0, 0, 0, 0, 0, 0, 0, 0, 0, 0, 0, 0, 0, 0, 0, 0},
 {0, 0, 0, 0, 0, 0, 0, 0, 0, 0, 0, 0, 0, 0, 0, 0, 0, 0, 0, 0, 0, 0, 0, 0, 0, 0, 0, 0, 0, 0, 0, 0, 0, 2, 0, 0, 0, 0, 0, 0, 0, 0, 0, 0, 0, 0, 0, 0},
 {0, 0, 0, 0, 0, 0, 0, 0, 0, 0, 0, 0, 0, 0, 0, 0, 0, 0, 0, 0, 0, 0, 0, 0, 0, 0, 0, 0, 0, 0, 0, 0, 0, 0, 4, 2, 0, 0, 0, 0, 0, 0, 0, 0, 0, 0, 0, 0},
 {0, 0, 0, 0, 0, 0, 0, 0, 0, 0, 0, 0, 0, 0, 0, 0, 0, 0, 0, 0, 0, 0, 0, 0, 0, 0, 0, 0, 0, 0, 0, 0, 0, 0, 0, 0, 2, 0, 0, 0, 0, 0, 0, 0, 0, 0, 0, 0},
 {0, 0, 0, 0, 0, 0, 0, 0, 0, 0, 0, 0, 0, 0, 0, 0, 0, 0, 0, 0, 0, 0, 0, 0, 0, 0, 0, 0, 0, 0, 0, 0, 0, 0, 0, 0, 0, 2, 0, 0, 0, 0, 0, 0, 0, 0, 0, 0},
 {0, 0, 0, 0, 0, 0, 0, 0, 0, 0, 0, 0, 0, 0, 0, 0, 0, 0, 0, 0, 0, 0, 0, 0, 0, 0, 0, 0, 0, 0, 0, 0, 0, 0, 0, 0, 0, 0, 2, 2, 0, 0, 0, 0, 0, 0, 0, 0},
 {0, 0, 0, 0, 0, 0, 0, 0, 0, 0, 0, 0, 0, 0, 0, 0, 0, 0, 0, 0, 0, 0, 0, 0, 0, 0, 0, 0, 0, 0, 0, 0, 0, 0, 0, 0, 0, 0, 0, 0, 0, 0, 0, 0, 0, 0, 0, 0},
 {0, 0, 0, 0, 0, 0, 0, 0, 0, 0, 0, 0, 0, 0, 0, 0, 0, 0, 0, 0, 0, 0, 0, 0, 0, 0, 0, 0, 0, 0, 0, 0, 0, 0, 0, 0, 0, 0, 0, 0, 0, 0, 0, 0, 0, 0, 0, 0},
 {0, 0, 0, 0, 0, 0, 0, 0, 0, 0, 0, 0, 0, 0, 0, 0, 0, 0, 0, 0, 0, 0, 0, 0, 0, 0, 0, 0, 0, 0, 0, 0, 0, 0, 0, 0, 0, 0, 0, 0, 2, 2, 0, 0, 0, 0, 0, 0},
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
 };

void calculate_error()
{

 int all_black_flag = 1; // assuming initially all black condition
 float weighted_sum = 0, sum = 0;
 float pos = 0;

 for (int i = 0; i < 5; i++)
 {
 if (lsa_reading[i] > BLACK_PATCH)
 {
 all_black_flag = 0;
 }
 weighted_sum += (float)(weights[i]) * (lsa_reading[i]);
 sum = sum + lsa_reading[i];
 }

 if (sum != 0) // sum can never be 0 but just for safety purposes
 {
 pos = weighted_sum / sum; // This will give us the position wrt line. if +ve then bot is facing left and if -ve the bot is facing to right.
 }

 if (all_black_flag == 1) // If all black then we check for previous error to assign current error.
 {
 if (prev_error > 0)
 {
 error = 3;
 }
 else
 {
 error = -3;
 }
 }
 else
 {
 error = pos;
 }
}
// end of function

void calculate_correction()
{
 error = error * 10; // we need the error correction in range 0-100 so that we can send it directly as duty cycle paramete
 difference = error - prev_error; // used for calcuating kd
 cumulative_error += error; // used for calculating ki

 cumulative_error = bound(cumulative_error, -30, 30); // bounding cumulative_error to avoid the issue of cumulative_error being very large
 correction = kp * error + ki * cumulative_error + kd * difference; // defined in http_server.c

 prev_error = error; // update error
}
// end of function

float bound(float val, float min, float max) // To bound a certain value in range MAX to MIN
{
 if (val > max)
 val = max;
 else if (val < min)
 val = min;
 return val;
}
// end of function

void Leftturn()
{

 int left = 1;
 
 while (left)
 {

 get_raw_lsa();

 if (lsa_reading[2] == 0)
 {
 rotation1 = 1;
 }
 
 set_motor_speed(MOTOR_A_0, MOTOR_BACKWARD, PWM);
 set_motor_speed(MOTOR_A_1, MOTOR_BACKWARD, PWM);

 if (lsa_reading[2] == 1000 && rotation1==1)
 {
 set_motor_speed(MOTOR_A_0, MOTOR_STOP, 0);
 set_motor_speed(MOTOR_A_1, MOTOR_STOP, 0);
 vTaskDelay(20 / portTICK_PERIOD_MS);
 Check_End=0;
 left_tune = 0;
 rotation1 = 0;
 left_turn_check=0;
 rotation2 = 0;
 left = 0;
 left_check = 0;
 right_check = 0;
 left_turn = 0;
 right_turn = 0;
 left_final_check=0;
 right_final_check=0;
 final_left_turn_check=0;
 final_right_turn_check=0;
 take_final_right_turn=0;
 take_final_left_turn=0;
 take_straight=0;
 stop=0; 
 printf("E\n");
 break;
 }
 vTaskDelay(10 / portTICK_PERIOD_MS);
 }
}


void Rightturn()
{

 printf("R T \n");
 int right = 1;

 while (right)
 {
 get_raw_lsa();

 if (lsa_reading[3] == 0)
 {
 rotation2 = true;
 }

 set_motor_speed(MOTOR_A_0, MOTOR_FORWARD, PWM);
 set_motor_speed(MOTOR_A_1, MOTOR_FORWARD, PWM);
 printf("CONTINUE R T \n");
 if (lsa_reading[2] == 1000 && lsa_reading[3] == 1000 && rotation2)
 {
 printf("STOP R T \n");
 set_motor_speed(MOTOR_A_0, MOTOR_STOP, 0);
 set_motor_speed(MOTOR_A_1, MOTOR_STOP, 0);
 rotation1 = 0;
 rotation2 = 0;
 only_right = 0;
 right_tune = 0;
 left_check = 0;
 right_check = 0;
 left_turn = 0;
 right_turn = 0;
 right = 0;
 left_final_check=0;
 right_final_check=0;
 final_left_turn_check=0;
 final_right_turn_check=0;
 take_final_right_turn=0;
 take_final_left_turn=0;
 take_straight=0;
 stop=0; 
 break;
 }
 vTaskDelay(10 / portTICK_PERIOD_MS);
 }
}

void straight()
{
 get_raw_lsa();
 calculate_error();
 calculate_correction();

 left_duty_cycle = bound((GOOD_DUTY_CYCLE - correction), MIN_DUTY_CYCLE, MAX_DUTY_CYCLE);
 right_duty_cycle = bound((GOOD_DUTY_CYCLE + correction), MIN_DUTY_CYCLE, MAX_DUTY_CYCLE);

 set_motor_speed(MOTOR_A_1, MOTOR_FORWARD, left_duty_cycle); /*goes forward in this case*/
 set_motor_speed(MOTOR_A_0, MOTOR_BACKWARD, right_duty_cycle);

 vTaskDelay(10 / portTICK_PERIOD_MS);
}


void final_straight()
{
 for (int k=0; k<24; k++)
 {
 get_raw_lsa();
 calculate_error();
 calculate_correction();

 left_duty_cycle = bound((GOOD_DUTY_CYCLE - correction), MIN_DUTY_CYCLE, MAX_DUTY_CYCLE);
 right_duty_cycle = bound((GOOD_DUTY_CYCLE + correction), MIN_DUTY_CYCLE, MAX_DUTY_CYCLE);

 set_motor_speed(MOTOR_A_1, MOTOR_FORWARD, left_duty_cycle); /*goes forward in this case*/
 set_motor_speed(MOTOR_A_0, MOTOR_BACKWARD, right_duty_cycle);
 printf("FINAL STRAIGHT");
 vTaskDelay(10 / portTICK_PERIOD_MS);
 }
 left_final_check=0;
 right_final_check=0;
 final_left_turn_check=0;
 final_right_turn_check=0;
 take_final_right_turn=0;
 take_final_left_turn=0;
 take_straight=0;
 stop=0;
}

void final_error_tuning()
{
 get_raw_lsa();
 calculate_error();
 calculate_correction();

 left_duty_cycle = bound((GOOD_DUTY_CYCLE - correction), MIN_DUTY_CYCLE, MAX_DUTY_CYCLE);
 right_duty_cycle = bound((GOOD_DUTY_CYCLE + correction), MIN_DUTY_CYCLE, MAX_DUTY_CYCLE);

 set_motor_speed(MOTOR_A_1, MOTOR_FORWARD, left_duty_cycle); /*goes forward in this case*/
 set_motor_speed(MOTOR_A_0, MOTOR_BACKWARD, right_duty_cycle);

 vTaskDelay(30 / portTICK_PERIOD_MS);
}

void final_left_turn()
{ 
 left_tune = 1;
 while (left_tune)
 {

 printf("leftcheckturn\n");
 get_raw_lsa();
 vTaskDelay(10 / portTICK_PERIOD_MS);
 if (lsa_reading[0] == 1000 && lsa_reading[2] == 1000)
 {
 printf("leftcheckcontinue\n");
 final_error_tuning();
 }
 else
 {
 Leftturn();
 }
 }

}

void final_right_turn()
{
 right_tune = 1;
 while (right_tune)
 {

 printf("rightcheckturn\n");
 get_raw_lsa();
 if (lsa_reading[4] == 1000 && lsa_reading[2] == 1000)
 {
 printf("rightcheckcontinue\n");
 final_error_tuning();
 }
 else
 {
 Rightturn();
 }
 }
}

void dijkstra()
{
    int sourceVertex = 1;
    int endVertex = 48;

    int dist[V];
    int sptSet[V];
    int parent[V];

    for (int i = 0; i < V; i++) {
    dist[i] = INT_MAX;
    sptSet[i] = 0;
    parent[i] = -1;
    }

    dist[sourceVertex - 1] = 0;

    for (int count = 0; count < V - 1; count++) {
    int minDist = INT_MAX;
    int minIndex = -1;

    for (int v = 0; v < V; v++) {
    if (sptSet[v] == 0 && dist[v] < minDist) {
    minDist = dist[v];
    minIndex = v;
    }
    }

    sptSet[minIndex] = 1;

    for (int v = 0; v < V; v++) {
    if (!sptSet[v] && costMatrix[minIndex][v] && dist[minIndex] != INT_MAX &&
    dist[minIndex] + costMatrix[minIndex][v] < dist[v]) {
    dist[v] = dist[minIndex] + costMatrix[minIndex][v];
    parent[v] = minIndex;
    }
    }
    }

    // Find and store the shortest path
    int currentVertex = endVertex - 1;
    int pathLength = 0;
    int pathArray[V];
    while (currentVertex != -1) {
    pathArray[pathLength] = currentVertex + 1; // Store 1-based index
    pathLength++;
    currentVertex = parent[currentVertex];
    }

    // Store the path in the final array
    int Array[pathLength];
    for (int i = 0; i < pathLength; i++) {
    Array[i] = pathArray[i];
    }

    
    int size2 = pathLength;

    int finalPathArr[size2]; // Create a new array to store the reversed order

    for (int i = 0; i < size2; i++) {
    finalPathArr[i] = Array[size2 - 1 - i]; // Copy elements in reverse order
    }

    // Print the reversed array
    for (int i = 0; i < size2; i++) {
    printf("%d ", finalPathArr[i]);
    }

    int z, a = 0,c=1,k,y=0;
    int dir[] = {1,4,1,2,2,1,4,1,4,1,2,1,1,4,1,4,1,4,3,4,3,4,3,2,3,2,3,4,4,2,3,4,3,4,4,1,1,4,4,1,4,1,4,1,4,1,4,1};

    int x = sizeof(dir) / sizeof(dir[0]);
    int size = sizeof(finalPathArr) / sizeof(finalPathArr[0]);
    int miss[size];


    for (int i = 0; i < size; i++)
    {
    if (finalPathArr[i + 1] - finalPathArr[i] > 1)
    {
    z = (finalPathArr[i + 1] - finalPathArr[i]) - 1;
    for (int j = 0; j < z; j++)
    {
    miss[a] = finalPathArr[i] + c;
    c++;
    a++;
    }
    c=1;
    }
    }
    // for (int i = 0; i < a; i++)
    // {
    // printf(" %d ", miss[i]);
    // }
    // printf(" \n%d ",x);

    for(int i=0;i<a; i++){
    k = miss[i];
    dir[k-1]=0;

    }
    for(int i=0;i<x;i++){
    printf(" %d ", dir[i]);
    }

    for(int i =0;i<x;i++){
    if(dir[i]!=0){
    final_run[y] = dir[i];
    y++;
    }
    }

    for(int i=0;i<y;i++){
    printf(" \n %d ", final_run[i]);
    }
    enable_path_matrix=0;

}

/*this function simplifies the direction array according to the simplified path*/
/*void simplified_direction()
{
 //int arr[] = {1, 2, 3, 4, 6, 8,11,13,16,17,18,20,22,23,24,25,27,30,31,33,34,35,37,40,42,44,46,48}, 

}
*/
// void path_matrix()
// {
// while(stop_path_matrix==1)
// {
// // Configuration of boot button 
// printf("Enter the total number of nodes: ");
// scanf("%d", &n);
// printf("Read the cost matrix:\n");
// for (i = 1; i <= n; i++) 
// {
// for (j = 1; j <= n; j++) 
// {
// scanf("%d", &cost[i][j]);
// if (cost[i][j] == 0)
// cost[i][j] = INFINITY_A;
// }
// }
// printf("Enter the source vertex: ");
// scanf("%d", &s);
// printf("Enter the end vertex: ");
// scanf("%d", &e);

// dijkstra(); //DIJKSTRA'S ALGORITHM FUNCTION

// printf("Shortest path from %d to %d is:\n", s, e);

// // Store the path in an array
// int current = e;

// while (current != s) {
// path[path_length++] = current;
// current = parent[current];
// }
// path[path_length++] = s;

// // Print the path in the correct order
// for (int i = path_length - 1; i >= 0; i--) {
// printf("%d", path[i]);
// if (i > 0) {
// printf(" --> ");
// }
// }

// printf("\nShortest distance: %d\n", dist[e]);
 
// simplified_direction();
// enable_path_matrix=0;
// stop_path_matrix=0;
// }
// }

void final_traversal()
{
 get_raw_lsa();
 if ((lsa_reading[0] == 1000) && (lsa_reading[1] == 1000) && (lsa_reading[2] == 1000))
 {
 // It detects PLUS NODE & Only Left Node
 printf("leftcheck1\n");
 left_final_check = 1;
 }
 // RIGHT 
 if ((lsa_reading[0] == 0) && (lsa_reading[3] == 1000) && (lsa_reading[2] == 1000) && (lsa_reading[4] == 1000))
 {
 printf("rightcheck1\n");
 right_final_check = 1;
 }
 
 if (left_final_check == 1 || right_final_check == 1)
 {
 vTaskDelay(10 / portTICK_PERIOD_MS);
 get_raw_lsa();
 
 printf("1: %d %d %d %d %d\n", lsa_reading[0], lsa_reading[1], lsa_reading[2], lsa_reading[3], lsa_reading[4]);
 if ((lsa_reading[0] == 1000) && (lsa_reading[1] == 1000) && (lsa_reading[2] == 1000)) // checks left first
 {
 final_left_turn_check = 1;
 final_right_turn_check = 0;
 left_final_check = 0;
 right_final_check = 0;
 printf("leftcheck2\n");
 }
 else if (lsa_reading[0] == 0 && lsa_reading[3] == 1000 && lsa_reading[2] == 1000 && lsa_reading[4] == 1000)
 {
 final_right_turn_check = 1;
 final_left_turn_check = 0;
 left_final_check = 0;
 printf("right_turn\n");
 right_final_check = 1;
 }
 else
 {
 left_turn_check = 0;
 final_right_turn_check = 0;
 final_left_turn_check = 0;
 right_final_check = 0;
 printf("leftcheck1failed\n");
 }
 }

 if (final_left_turn_check == 1 || final_right_turn_check == 1)
 {
 //printf("%d ",final_run[i]);
 printf("final_left_right_turn_check\n");
 printf("\n final:%d:", final_run[f] );
 printf("\n final-1:%d:", final_run[f-1]);
 printf("\n f=%d", f);
 
 if (final_run[f] == 0)
 {
 printf("stop\n");
 stop=1;
 }
 else if ((final_run[f] - final_run[f - 1] == -1) || (final_run[f] - final_run[f - 1] == 3)) //LEFT
 {
 printf("take_final_left_turn\n");
 take_final_left_turn=1;
 f++;
 }
 else if ((final_run[f] - final_run[f - 1] == 1) || (final_run[f] - final_run[f - 1] == -3)) //RIGHT
 {
 printf("take_final_right_turn\n");
 take_final_right_turn=1;
 f++;
 }
 else if (final_run[f] - final_run[f - 1] == 0) //STRAIGHT
 {
 printf("take_straight2\n");
 take_straight=1;
 f++;
 } 

 }

 if(take_final_left_turn==1)
 {
 printf("take_final_right_turn2\n");
 final_left_turn();
 }
 else if(take_final_right_turn==1)
 {
 printf("take_final_left_turn2\n");
 final_right_turn();
 }
 else if(take_straight==1)
 {
 printf("take_straight_final\n");
 final_straight(); 
 }
 
 else if (stop==1)
 {
 printf("take_stop_final\n");
 while (1)
 {
 set_motor_speed(MOTOR_A_0, MOTOR_STOP, 0);
 set_motor_speed(MOTOR_A_1, MOTOR_STOP, 0);

 vTaskDelay(10 / portTICK_PERIOD_MS);
 }
 }
}


void line_follow_task(void *arg)
{

 while (1)
 { 
 while(enable_path_matrix==1)
 {
  dijkstra();
 } 
 final_traversal();
 straight();
 vTaskDelay(10 / portTICK_PERIOD_MS);
 }
}



void app_main()
{
 
 ESP_ERROR_CHECK(enable_lsa());
 ESP_ERROR_CHECK(enable_motor_driver());

 xTaskCreate(&line_follow_task, "line_follow_task", 4096, NULL, 1, &taskhandle1);
}

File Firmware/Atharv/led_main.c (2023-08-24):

#include <stdio.h>
#include "freertos/FreeRTOS.h"
#include "freertos/task.h"
#include <driver/gpio.h>
#include "esp_log.h"
#define led1 12
#define led2 33
#define led3 25
#define led4 26
#define led5 27
#define led6 14
#define led7 13
#define led8 23
void get_led(uint8_t data,const int *pin_out)
{
for(int i=0;i<8;i++)
{
if ((data & 0x80) == 0x80)
            {
                // set gpio value to 1
                gpio_set_level((gpio_num_t)pin_out[i], 1);
            }
            else
            {
                // set gpio value to 0
                gpio_set_level((gpio_num_t)pin_out[i], 0);
            }
            data= data<<1;
            }
            }
void app_main(){
static const int pin_out[8] = {led1,led2,led3,led4,led5,led6,led7,led8};
uint8_t data;
static const char *TAG = "blink_code";
uint64_t bit_mask = 0;
bit_mask = (1ULL<<led1) | (1ULL<<led2) | (1ULL<<led3) | (1ULL<<led4) | (1ULL<<led5) | (1ULL<<led6) | (1ULL<<led7) | (1ULL<<led8);
gpio_config_t io_conf;
io_conf.pin_bit_mask = bit_mask;
io_conf.mode = GPIO_MODE_OUTPUT;
io_conf.pull_up_en =0;
io_conf.pull_down_en = 1;
io_conf.intr_type = GPIO_INTR_DISABLE;

esp_err_t err = gpio_config(&io_conf);
if(err == ESP_OK){
for(int a=0;a<5;a++){
get_led(0xFF,pin_out);
vTaskDelay(1000 / portTICK_RATE_MS);
get_led(0x00,pin_out);
vTaskDelay(1000 / portTICK_RATE_MS);
}
data = 0x01;
while(1)
{
if(data == 0x00){
data = 0x01;
}
get_led(data,pin_out);
data=data<<1;
vTaskDelay(1000 / portTICK_RATE_MS);
}
}
  else
    {
        ESP_LOGE(TAG, "error: %s", esp_err_to_name(err));
        return;
      }
      }

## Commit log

2023-10-27 Started with PCB design documentation
2023-10-27 Update PCB images
2023-10-30 added some conditions to avoid miss identification of node
    [1_left_follow_rule.c]
2023-10-30 Update PCB design documentation
2023-10-31 Updatefeatures of pcb4
2023-10-31 Update features of pcb
2023-10-31 Added Major changes for PCB
2023-10-31 push pcb design files
    [BK-18650-PC2.step, CON-SOCJ-2155--3DModel-STEP-56544.STEP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]
2023-11-01 upload lsa pcb design task
    [lsa_task.kicad_pcb, lsa_task.kicad_sch]
2023-11-01 push lsa task pcb design files
    [TCRT5000.step]
2023-11-01 push final lsa pcb design files
    [TCRT5000.step]
2023-11-02 Update PCB documentation
2023-11-03 Create pcb task documentation
2023-11-03 added documentation for led blink task
2023-11-03 added pcb images and task videos
2023-11-03 added all the images of PCB design and implementation of algorithm videos.
2023-11-03 Update Problems with current algorithm
2023-11-05 update pcb model
